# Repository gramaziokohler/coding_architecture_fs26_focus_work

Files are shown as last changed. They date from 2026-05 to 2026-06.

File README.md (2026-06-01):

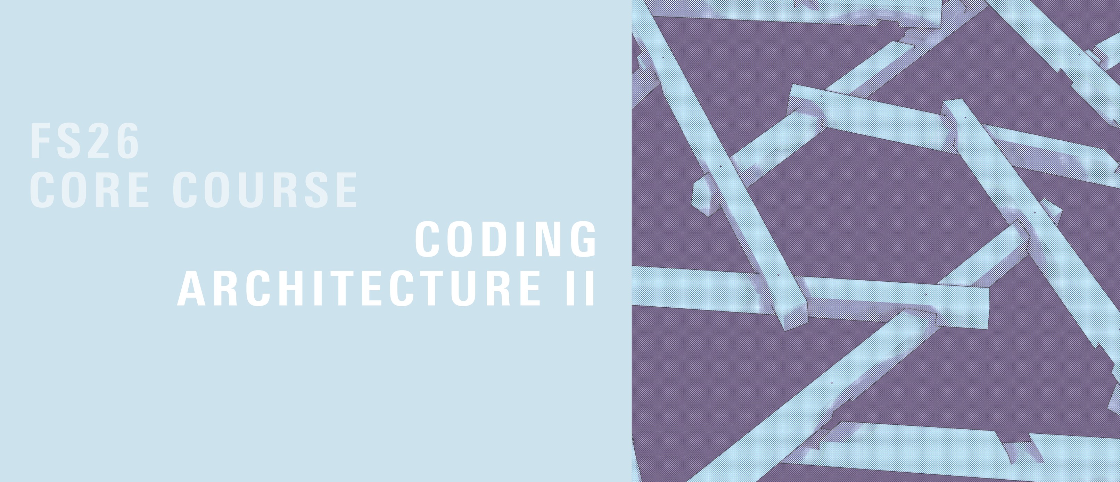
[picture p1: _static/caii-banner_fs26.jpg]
Banner


# Coding Architecture II: Focus Work

> **We are starting!**

Welcome to the **Focus Work** of Coding Architecture II, Spring Semester 2026! 

Following an intensive design phase, this repository focuses on the translation of the **winning project** into a real-world, full-scale timber structure. Over the next four weeks, we will adapt, refine, fabricate, and assemble the reciprocal frame structure for the local neighborhood garden (*Quartiergarten*).

This phase bridges the gap between computational design and physical reality, requiring a fabrication- and assembly-aware mindset from day one.

## Table of Contents
1. [Focuswork Overview & Schedule](#focuswork-overview--schedule)
   - [Week 1: Revision & Detailing](#week-1-revision--detailing)
   - [Week 2: Preparation & Machine Instructions](#week-2-preparation--machine-instructions)
   - [Week 3: Fabrication & Prefabrication](#week-3-fabrication--prefabrication)
   - [Week 4: On-Site Assembly](#week-4-on-site-assembly)
2. [Workflow & Team Structure](#workflow--team-structure)
   - [Dynamic Deliverables](#dynamic-deliverables)
3. [Repository Structure](#repository-structure)
   - [Working Folders vs. Deliverables](#working-folders-vs-deliverables)
   - [Group 3's Approach and changes to the default solution](#group-3s-approach-and-changes-to-the-default-solution)

---

## Focuswork Overview & Schedule

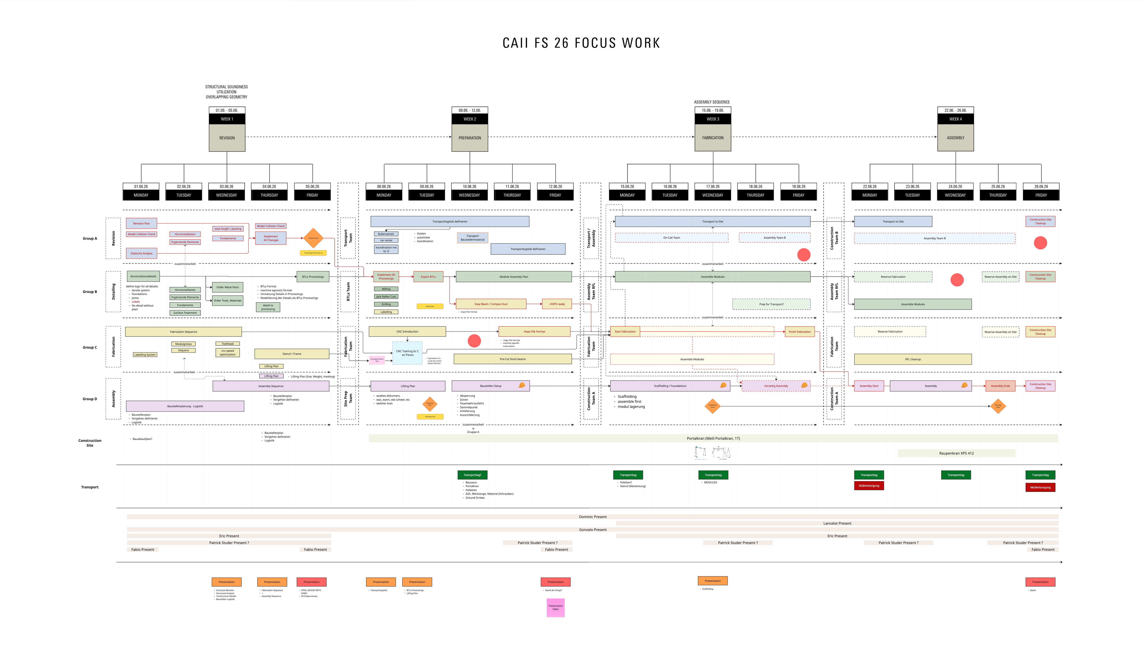
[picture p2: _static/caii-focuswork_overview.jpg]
Focus Work Overview


The Focus Work spans exactly 4 weeks (20 full working days), taking us from design refinement all the way to the final construction and Apero.

### Week 1: Revision & Detailing
**Goal: Design Freeze, Timber Model & BTLX Extraction**
* Integrate direct feedback and wishes from the *Quartiergarten* community.
* Resolve structural analysis and finalize construction details (foundations, connections, joints).
* Establish the fabrication and assembly sequence, including site planning and logistics.
* Design the physical template (*Schablone*) for pinpoint foundation placement.

### Week 2: Preparation & Machine Instructions
**Goal: System Ready for Fabrication**
* Prepare the CNC machine instructions and dive into the HOPS file format.
* Pre-cut all raw beams to their required stock length.
* Finalize the modular subdivision of the structure.
* Plan exact sequences, define transport logistics, and order the final remaining parts.

### Week 3: Fabrication & Prefabrication
**Goal: Transport-Ready Modules**
* Produce the foundation template and machine all custom timber parts.
* Assemble the parts into pre-fabricated modules simultaneously in the lab.
* Label all elements systematically and pack them to be transport-ready.

### Week 4: On-Site Assembly
**Goal: Full-Scale Construction**
* Transport all modules to the site.
* Use the template for accurate foundation placement.
* Assemble the modules into the final structure in a single day using a crane.
* Site teardown, tool cleanup, and concluding with a well-deserved Apero! 🍻

---

## Workflow & Team Structure

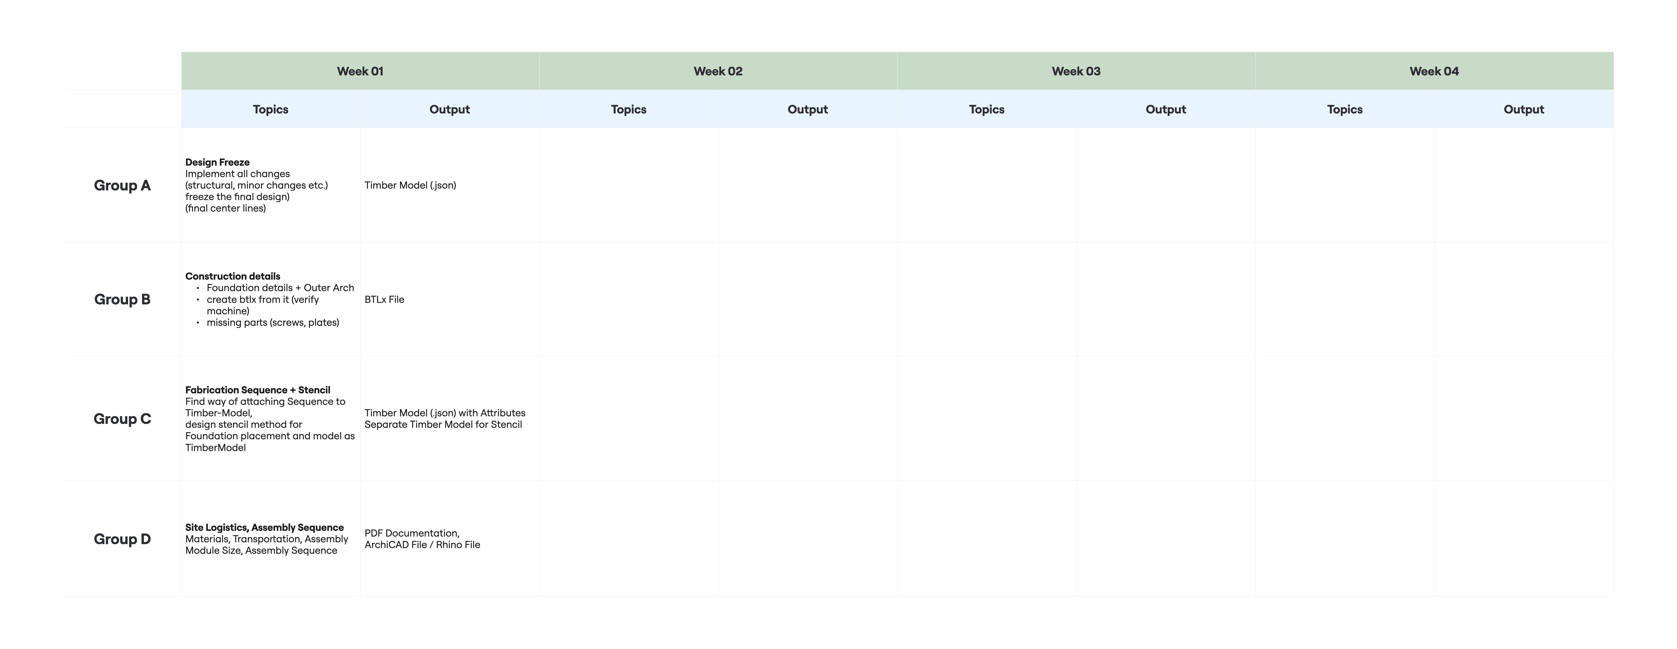
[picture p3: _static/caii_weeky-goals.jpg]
Weekly Goals


> *Note: This image will be updated soon.*

The cohort is divided into **4 Groups (A, B, C, D)**. 

To foster leadership and project management skills, **each group takes the primary responsibility for one specific week**, coordinating the tasks and ensuring the milestones are met.
    
### Dynamic Deliverables
Weekly deliverables will be announced on a rolling basis. The workflow will adapt to the reality of the project: sometimes it will be linear, sometimes circular and iterative. There will be highly intense periods and more relaxed ones. **Flexibility, communication, and teamwork are our most important tools.**

You will work across the organized sub-directories (`working_directory/group_a/`, `working_directory/group_b/`, `working_directory/group_c/`, `working_directory/group_d/`) and will heavily interact and hand off tasks between groups.

## Repository Structure

To keep the repository organized despite the dynamic and sometimes chaotic nature of the Focus Work, we strictly separate **work in progress** from **official milestones**. 

```text
coding_architecture_fs26_focus_work/
├── _static/             # Static files and assets for documentation
├── code/                # Core Python scripts and GH definitions
├── deliverables/        # Official weekly handovers
│   ├── week_01/
│   ├── week_02/
│   └── ...
├── design/              # Rhino files and base geometries
├── images/              # Additional project and progress images
├── timber_models/       # Exports of finalized timber objects/models
└── working_directory/   # Sandboxes for the groups
    ├── group_a/         # Working directory for Group A
    ├── group_b/         # Working directory for Group B
    ├── group_c/         # Working directory for Group C
    └── group_d/         # Working directory for Group D
```

### Working Folders vs. Deliverables
* **`working_directory/group_*/` Folders:** Your primary sandbox. This is where your group edits scripts, tests parametric components, experiments with new tools, and saves intermediate Grasshopper files. Each group has full ownership over their folder.
* **`deliverables/week_XX/` Folders:** At the end of each week, the responsible lead group compiles the finalized code, the frozen Rhino models, fabrication files (like BTLX/HOPS), and logistic lists into the respective week's folder. This guarantees a clean, linear history of our progress without the clutter of daily work.
* **`code/` & `design/`:** Shared global resources. The `code/` folder contains the core algorithmic pipeline that we refine together.

### Group 3's Approach and changes to the default solution
The codebase provided here is based on the winning design from the semester. Group 3 distinguished themselves by heavily extending our standard reciprocal frame template to bridge the gap between automated generation and manual control. Here is how their approach stands out and which files drive it:
    
1. **Dual-Mesh Generation:** Instead of applying one algorithm to the whole structure, they generate a hexagonal mesh for the interior beams and a quad mesh for the boundary beams.
2. **Custom RF Logic (`a03_rf_system_timo.py`):** They authored custom reciprocal frame logic for the inner beams to introduce specifically tailored hexagonal eccentricity and beam extensions, while keeping the boundary beams simple (`a03_rf_system.py`).
3. **Interactive Line Editing (C# Component):** They merged the beams (`a03_line_cleaner.py`), extracted the pure centerlines, and passed them into a custom C# Grasshopper component. This script creates an interactive GUI in Rhino (with custom Snaps and a mini-Gumball) that allows developers to manually drag and adjust specific beam endpoints visually.
4. **The Hybrid System (`a03_rf_system_hybrid.py`):** Because moving independent lines manually breaks the original continuous mesh topology, they wrote a script that intelligently pieces the edited loose lines back together into a valid, combined `RFSystemHybrid` mesh graph.
5. **Custom Foundation Rules:** By subclassing the default timber model creator, we have started to implemented specific rules to automatically identify foundation beams (beams lying horizontally near `z=0`), assign them a stronger 110x120 cross-section, and apply specific structural joints.

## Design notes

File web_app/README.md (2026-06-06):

# Vue 3 + Vite

This template should help get you started developing with Vue 3 in Vite. The template uses Vue 3 `<script setup>` SFCs, check out the [script setup docs](https://v3.vuejs.org/api/sfc-script-setup.html#sfc-script-setup) to learn more.

Learn more about IDE Support for Vue in the [Vue Docs Scaling up Guide](https://vuejs.org/guide/scaling-up/tooling.html#ide-support).

## Regenerate `web_data` from a TimberModel

The web app does not read `timber_models/*.json` directly. It reads the split
viewer export in `web_data/`:

- `web_data/structure.json`
- `web_data/beams/<beam_id>/<beam_id>.json`
- `web_data/beams/<beam_id>/<beam_id>.stl`

For final joinery geometry, use the Grasshopper component script:

```text
code/gh_compont_scripts/gh_export_web_data.py
```

It takes the live TimberModel object, runs inside Rhino, and can therefore use
`model.process_joinery()` and `beam.geometry` with Rhino's BRep backend.

To regenerate that folder from a TimberModel JSON:

```bash
python ../code/export_web_data.py ../timber_models/timber_model_friday-3.json --output ../web_data --clean
```

By default the exporter uses `--geometry-source auto`: it tries to load the
TimberModel with COMPAS Timber, runs `model.process_joinery()`, and writes STL
files from each processed `beam.geometry`. If COMPAS Timber is not available, or
if a beam geometry cannot be converted to a mesh, that beam falls back to a
rectangular STL from `frame`, `length`, `width`, and `height`.

To require real COMPAS Timber geometry and fail instead of falling back:

```bash
python ../code/export_web_data.py ../timber_models/timber_model_friday-3.json --output ../web_data --clean --geometry-source compas
```

When using the Rhino 8 Python site env on Apple Silicon, run the x86_64 Python
because the installed binary packages are x86_64:

```bash
PYTHONPATH=/Users/lorinwiedemeier/.rhinocode/py39-rh8/site-envs/ca-fs26-focus-work-p_hXDUpu \
arch -x86_64 /Users/lorinwiedemeier/.rhinocode/py39-rh8/python3.9 \
../code/export_web_data.py ../timber_models/timber_model_friday-3.json --output ../web_data --clean
```

If this prints `PluginNotInstalledError` for `Brep`, the script is running
outside a Rhino context and COMPAS cannot evaluate the final BRep geometry. In
that case the exporter still writes metadata and box fallback STLs, but final
joinery STLs need to be exported from inside Rhino/GH or from a Python runtime
with a working COMPAS BRep plugin.

The exporter first looks for beam identity values in beam attributes, so Group C
can later store names/modules/numbers there without changing the rest of the
export. The fallback naming is sequential and uses:

```bash
--module-sizes A:36,B:31,C:30,D:27,E:27,F:31
```

The script writes valid STL files. In an environment with COMPAS Timber, those
STLs should include processed joinery. Outside that environment, the STL fallback
is only the rectangular beam volume.

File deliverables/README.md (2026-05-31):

# Deliverables & Submission Table

| Group | Week 01 |
| :--- | :--- |
| **Group A** | **Topics:**<br>- Design Freeze<br>- Implement Changes/Adjustments from Quartiergarten (by tuesday evening)<br>- Implement Structural Analysis results (starting wed or thu)<br>- Collision Checks<br>- Setup a clean Timbermodel creation in coordination with Group B<br>- Ensure all joints are drawn properly (Linked to Group B)<br>- Ensure foundations and outer arch can be controlled separately (Linked to Group B)<br>- Design Decisions: definitive orientation and placement, definitive size and shape<br>- DESIGN FREEZE!<br><br>**Output:**<br>- Timber Model (.json)<br>- Grasshopper file (.ghx)<br>- Karamba-Mesh (.3dm)<br>- RSTAB File (.rs9) |
| **Group B** | **Topics:**<br>- Construction details<br>- Define & implement details: foundation (Linked to Group A), outer arch (Linked to Group A)<br>- Create processings<br>- Predrillings<br>- Name engravings (Linked to Group C)<br>- Export BTLx<br>- Order assembly parts (screws, plates)<br><br>**Output:**<br>- TimberModel (.json)<br>- Grasshopper (.ghx)<br>- Machining File (.btlx) |
| **Group C** | **Topics:**<br>- Fabrication Sequence + Stencil<br>- Define a way of attaching fabrication sequence to Timber-Model<br>- Define fabrication-module size (Linked to Group D)<br>- Define fabrication sequence (Linked to Group D)<br>- Design stencil method for Foundation placement and model as TimberModel<br>- Create naming convention for elements and modules<br><br>**Output:**<br>- Timber Model (.json) with Attributes<br>- GH File (.ghx) w/ Sequencing<br>- Explanatory animation or diagram<br>- Separate Timber Model for Stencil |
| **Group D** | **Topics:**<br>- Site Logistics, Assembly Sequence<br>- Plan for materials and transportation<br>- Define assembly-module size (Linked to Group C)<br>- Plan assembly sequence (Linked to Group C)<br>- Create transportation plan, assembly plan, construction site plan<br><br>**Output:**<br>- PDF Documentation (.pdf)<br>- A2 Plot of Plan (physical)<br>- Grasshopper file (.ghx)<br>- ArchiCAD File / Rhino File (.pln / .3dm) |

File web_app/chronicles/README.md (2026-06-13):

# Hardleaf — Coding Chronicles

A 3D skyline visualization of the Hardleaf repository's evolution. Each tower is a
commit; height is lines changed, color is the add/delete balance, and the camera
flies down the avenue of time while commit messages surface in the ticker.

## How the data flow works

The page loads `commits.json` (fetched next to `index.html`) on open. That file is
**generated by a GitHub Action and published with the Pages deployment** — it is
never committed to the repository. If `commits.json` is missing (e.g. opening the
HTML locally), the page falls back to built-in demo data, so it always renders.

This app does **not** have its own Pages deployment. GitHub Pages allows only one
deployment per repo, and that slot is owned by the main `web_app` (Vite) site. To
avoid clobbering it, the skyline is built as a step inside the main deploy workflow
and dropped into a `chronicles/` subfolder of the main app's `dist/`:

```
repo/
├─ web_app/
│  └─ chronicles/
│     ├─ index.html              # this page (deployed at /chronicles/index.html)
│     ├─ build-commits.mjs       # generates commits.json from git history
│     └─ README.md               # you are here
└─ .github/workflows/
   └─ deploy.yml                 # builds web_app + this skyline, deploys both
```

The relevant steps in [`.github/workflows/deploy.yml`](../../.github/workflows/deploy.yml):

```yaml
- uses: actions/checkout@v4
  with:
    fetch-depth: 0              # generator needs full commit history
# ...build main app into web_app/dist...
- run: |
    mkdir -p web_app/dist/chronicles
    cp web_app/chronicles/index.html web_app/dist/chronicles/index.html
    node web_app/chronicles/build-commits.mjs --out web_app/dist/chronicles/commits.json
```

So the main app stays at the site root and the skyline is served at the
`/chronicles/` subpath, e.g.
`https://<owner>.github.io/coding_architecture_fs26_focus_work/chronicles/`.
Because the page fetches `./commits.json` (relative), the subpath needs no code change.

The workflow runs on every push to `main`, once daily, and on manual dispatch, so the
skyline stays current with no manual step.

## Local preview

`commits.json` won't exist locally, so the page shows demo data. To preview against
real data, generate it yourself and serve the folder (a plain file:// open will not
fetch JSON in some browsers):

```bash
# from web_app/chronicles/
node build-commits.mjs --out commits.json
python3 -m http.server 8000     # then visit http://localhost:8000/index.html
```

## Options

- **Full history vs. trailing month.** The workflow generates full history by
  default. For only the last 30 days, change the generate step in `deploy.yml` to:
  `node web_app/chronicles/build-commits.mjs --since "30 days ago" --out web_app/dist/chronicles/commits.json`
- **Manual override.** The "Load your repo" drawer in the page still works for
  pasting any `git log` output by hand.

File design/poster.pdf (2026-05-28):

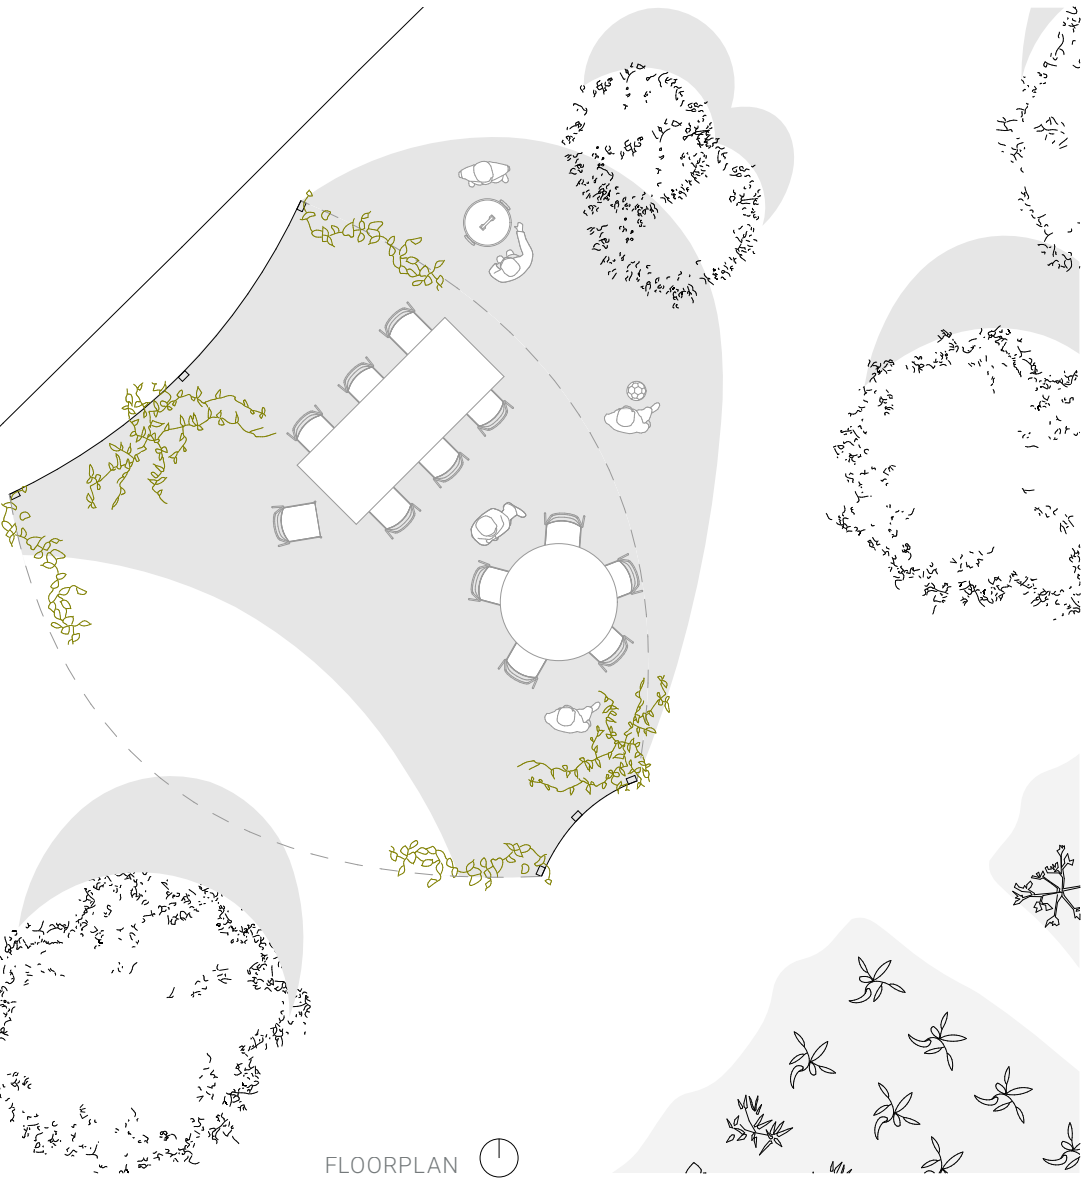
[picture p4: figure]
FLOORPLAN

GSEducationalVersion

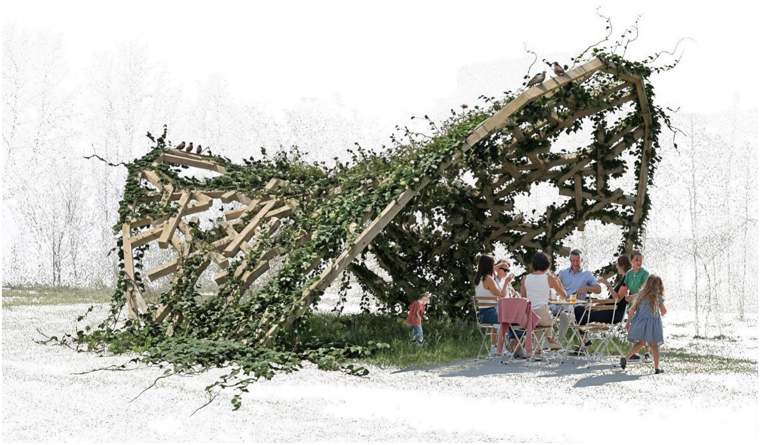
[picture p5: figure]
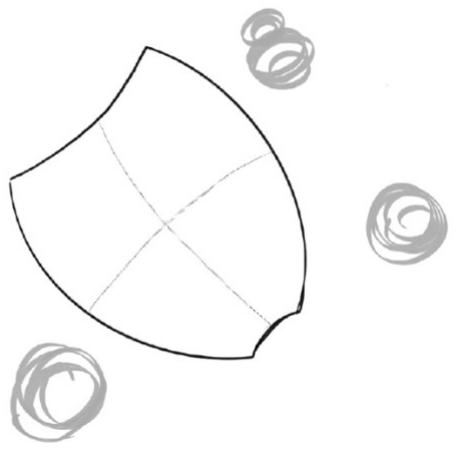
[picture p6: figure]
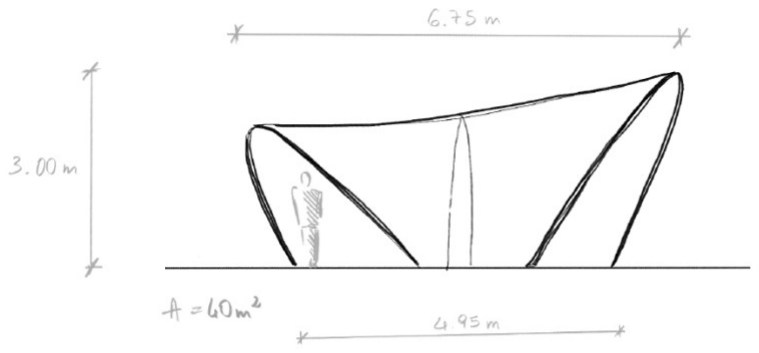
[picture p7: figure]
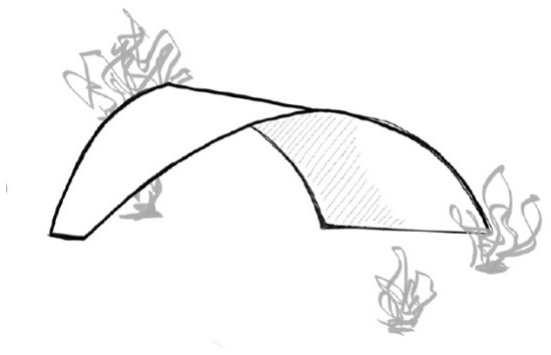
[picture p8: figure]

SKETCHES

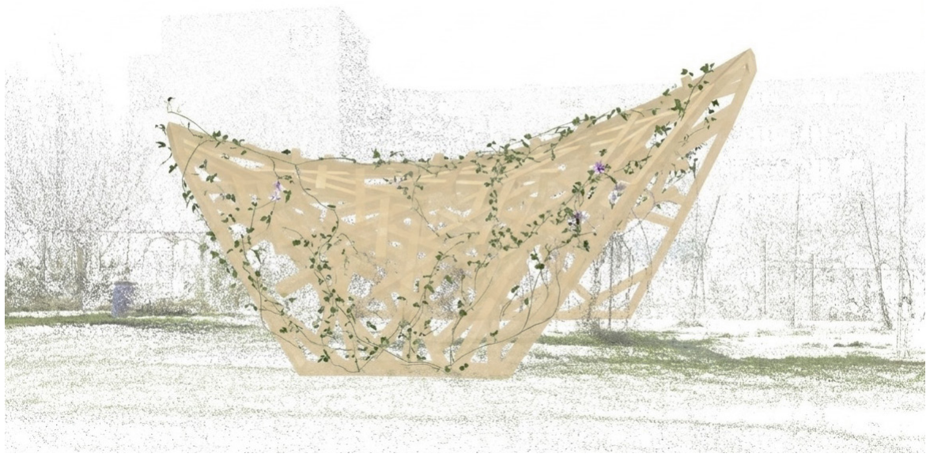
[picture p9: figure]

MESHING WORKFLOW

The pavilion was conceived through a design process focused on preserving and enhancing the existing vegetation of the garden. Particular attention was given to the plum tree and the banana trees, which emerged during the site visit as important and valued elements of the space. Rather than imposing a new object onto the site, the project was developed as an organic intervention integrated around the presence of these plants.

As the design evolved, the geometry was refined to maximize shaded areas and improve environmental comfort. This led to the development of a leaf-shaped configuration, characterized by variations in height and a wider canopy capable of providing extensive coverage while maintaining a projected area of 40 m². The pavilion retains a clear and simple structural logic based on two load-bearing sides: a longer structural edge positioned parallel to the existing fence at the back of the garden, and a shorter side at the front, opening the pavilion towards the landscape.

The orientation of the structure directly informs its form. On the south side, the pavilion remains lower in height to strengthen protection from direct sunlight, working together with the natural shade provided by the nearby plum tree. Towards the north, the structure gradually opens and rises, creating a lighter and more permeable spatial condition.

The covered area was intentionally designed as a wide and open space, ensuring flexibility and adaptability for different uses over time. The pavilion can accommodate tables, gatherings, workshops, or temporary installations, while remaining open to future transformations and changing configurations of plants within the garden.

The project also responds to the current condition of the kiwi plants located in the center of the site. Since relocating them immediately may not be possible, the pavilion allows for multiple scenarios: the plants can temporarily remain within the open interior space or later be repositioned along the structural base, where they could continue growing integrated with the pavilion itself while keeping the central area unobstructed.

# HARD LEAF

TIMO FEDDERN, ZAN KOCUNIK, ALESSIA MARTINO
GROUP 03 / CODING ARCHITECTURE II / FS26

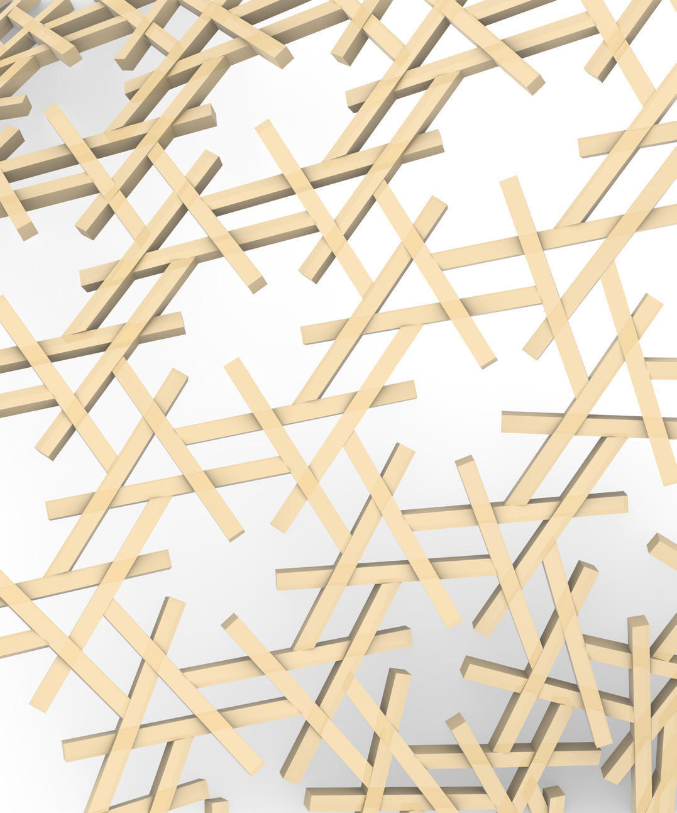
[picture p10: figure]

The | reciprocal | frame
structure | is | generated
through an organic meshing system derived from a
hexagonal pattern. Starting from a regular geometric grid, the mesh was progressively transformed and adapted to create a more fluid and natural configuration. The resulting network combines order and irregularity: the hexagonal geometry provides structural continuity and stability, while the variation in orientation and density creates a lighter, more dynamic spatial effect. The differentiated density of the mesh also allows the structure to accommodate
multiple configurations of hanging plants and climbing vegetation, creating areas with varying levels of shade, openness, and interaction
with the surrounding garden.

View in AR!

QUARTIERGARTEN HARD, ZURICH

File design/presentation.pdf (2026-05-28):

# group 03

# Timo Feddern, Zan Kocunik, Alessia Martino

## Quartiergarten Hard Project Proposal

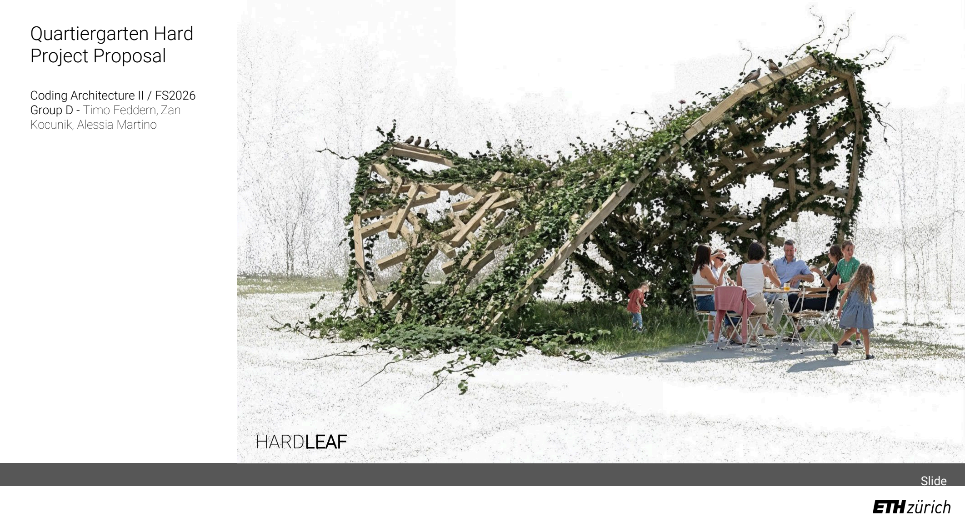
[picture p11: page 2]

Slide

## HARDLEAF

Coding Architecture II / FS2026 Group D - Timo Feddern, Zan Kocunik, Alessia Martino

## Design process

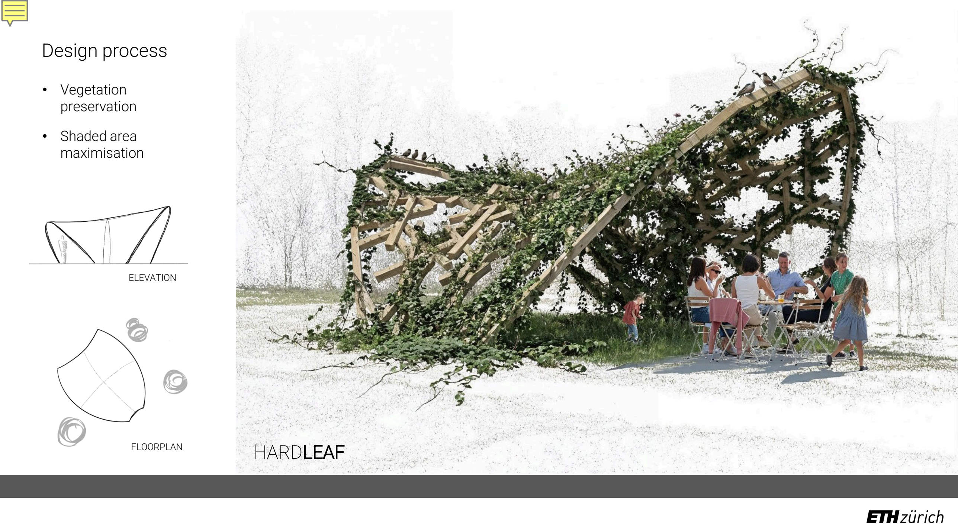
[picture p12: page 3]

## HARDLEAF

- Vegetation
preservation
- Shaded area
maximisation

ELEVATION

FLOORPLAN

## Context

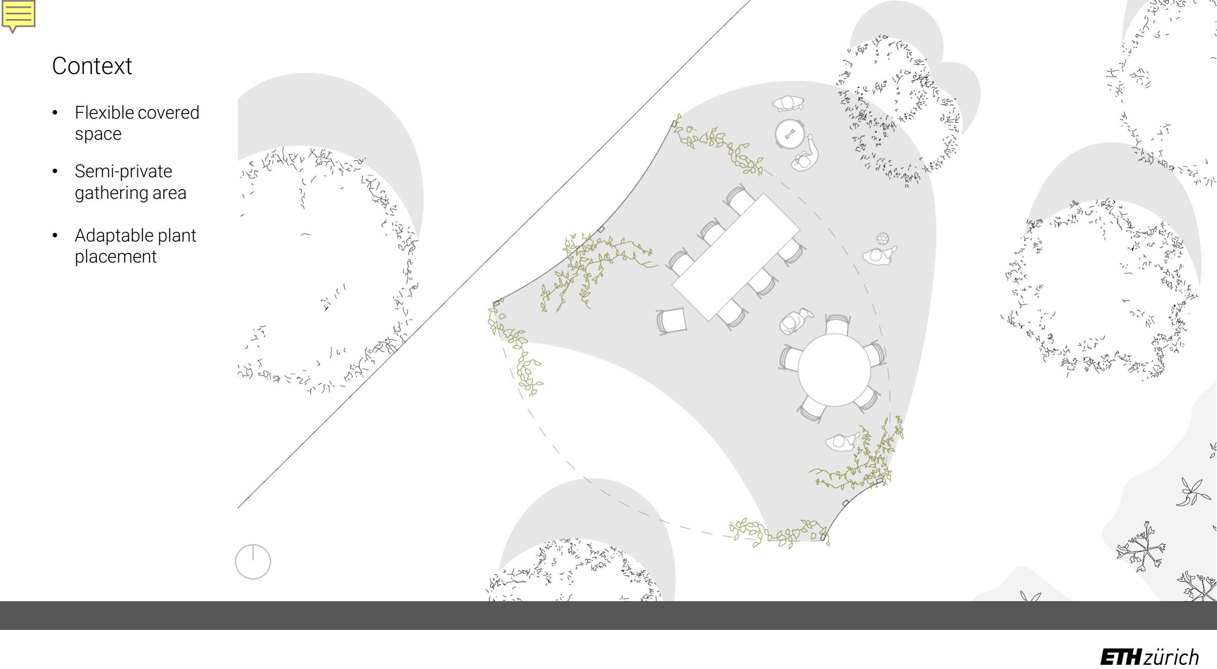
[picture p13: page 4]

- Flexible covered
space
- Semi-private
gathering area
- Adaptable plant
placement

## Exposure

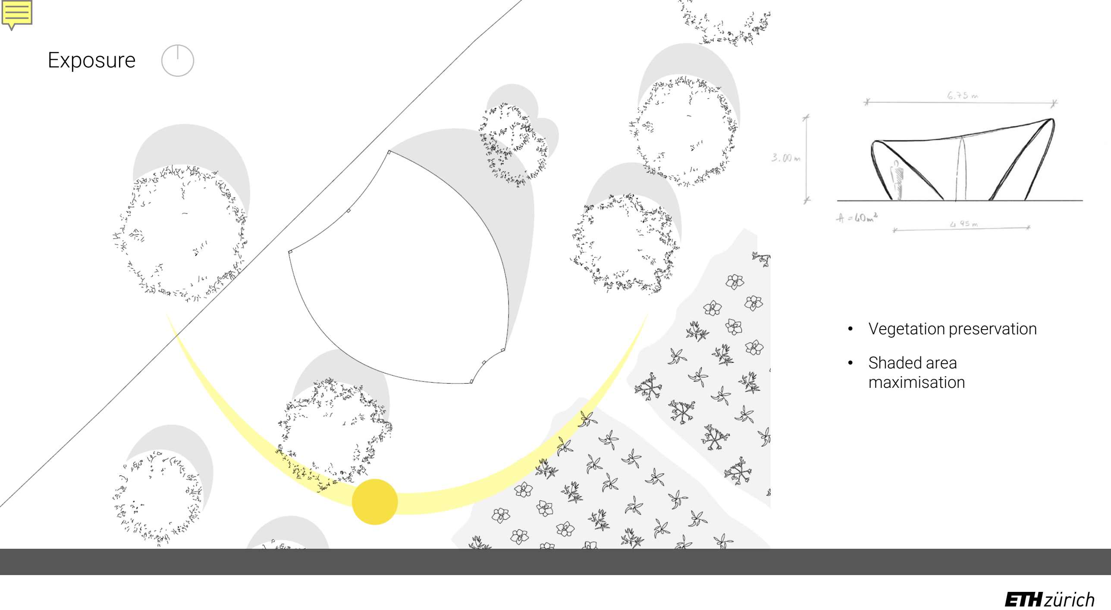
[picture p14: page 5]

- Vegetation preservation
- Shaded area
maximisation

## Reciprocal frame system

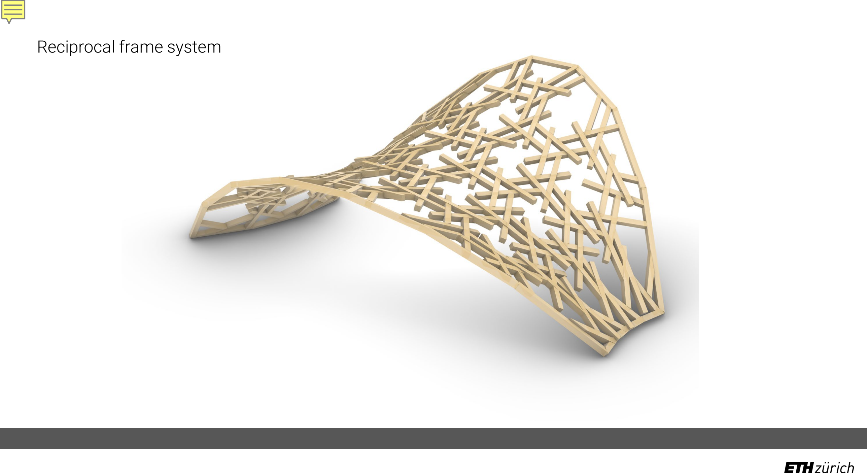
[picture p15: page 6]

## Meshing workflow

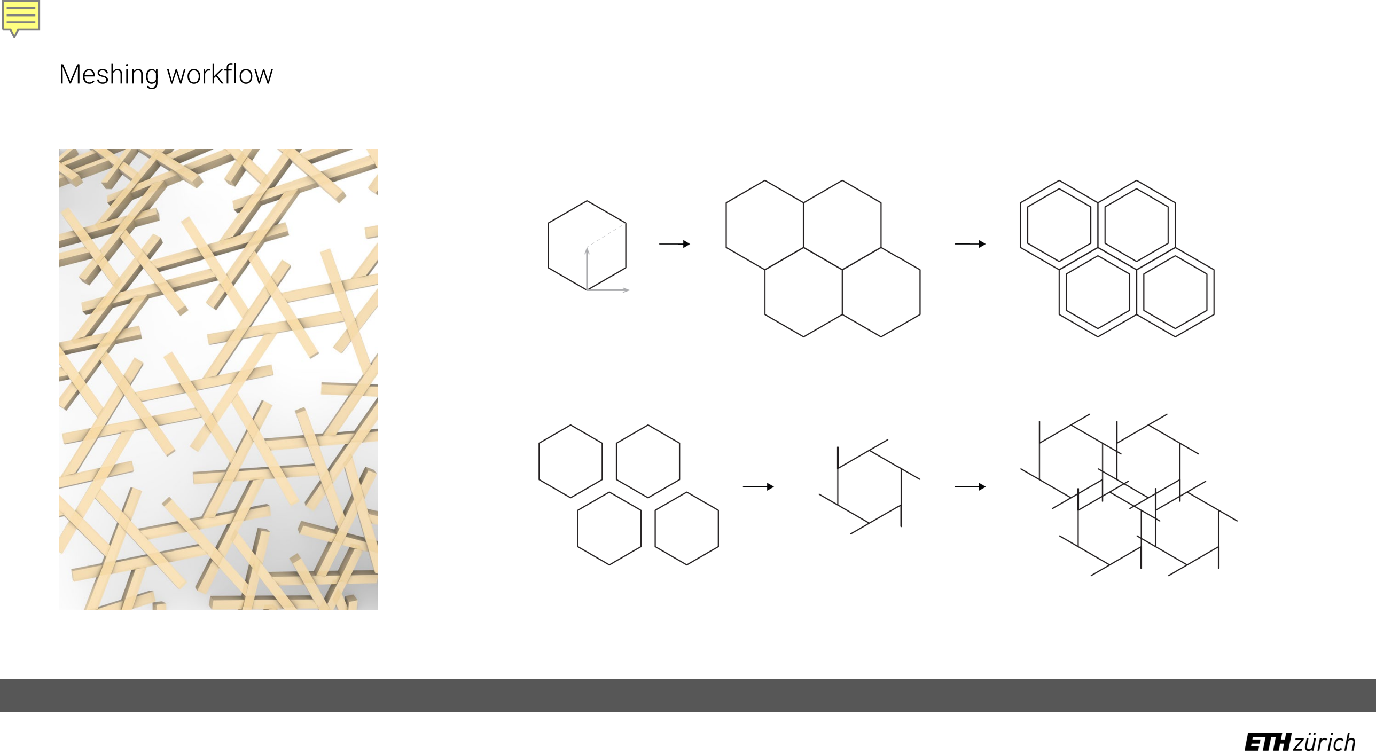
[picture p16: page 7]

## Shading

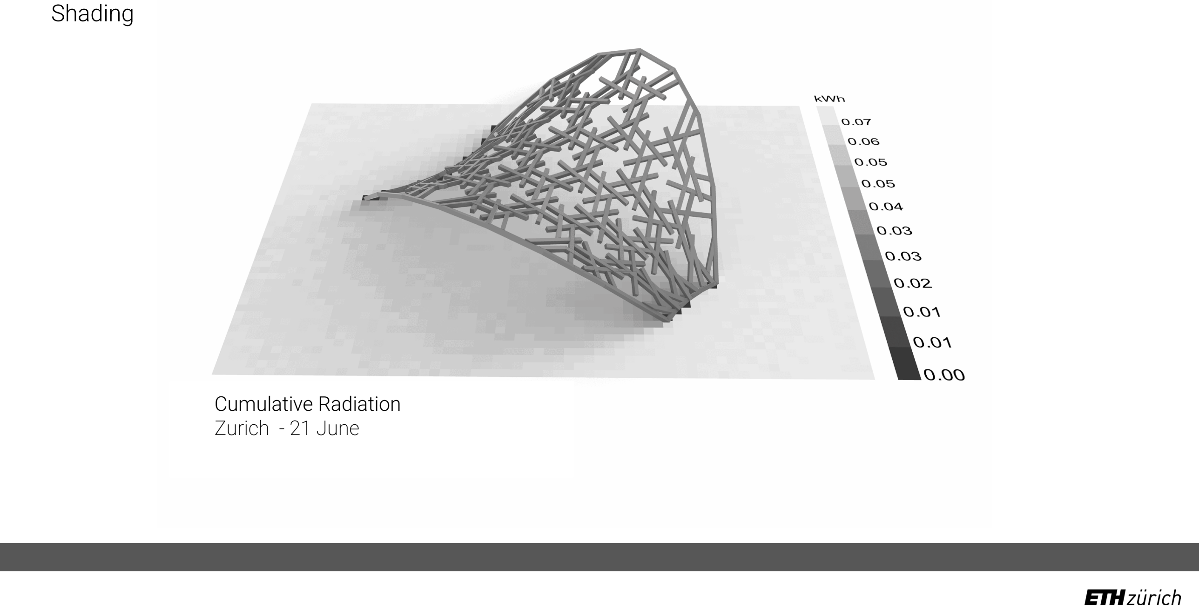
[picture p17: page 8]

Cumulative Radiation
Zurich - 21 June

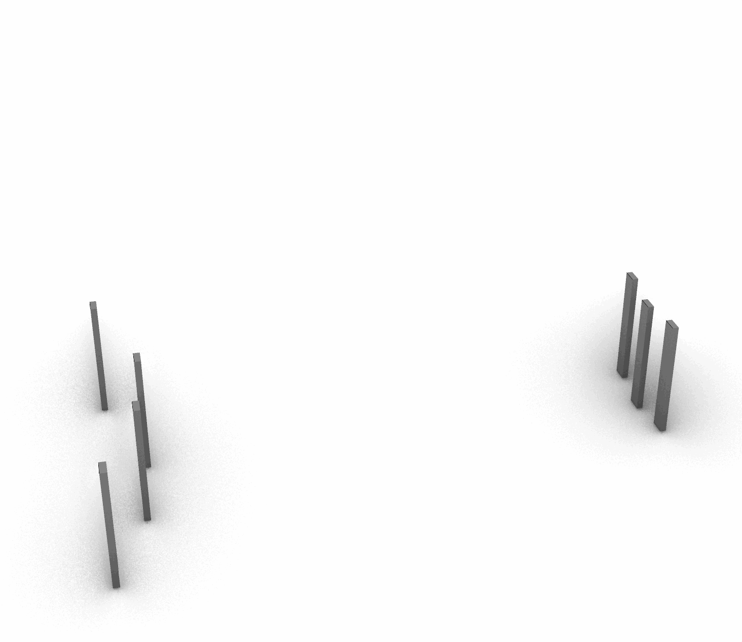
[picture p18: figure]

## Assembling

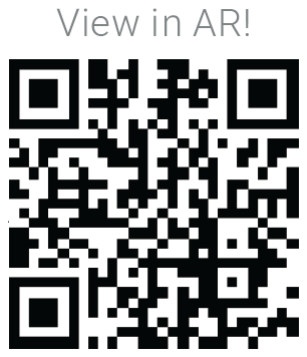
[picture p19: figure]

Thank you for your attention

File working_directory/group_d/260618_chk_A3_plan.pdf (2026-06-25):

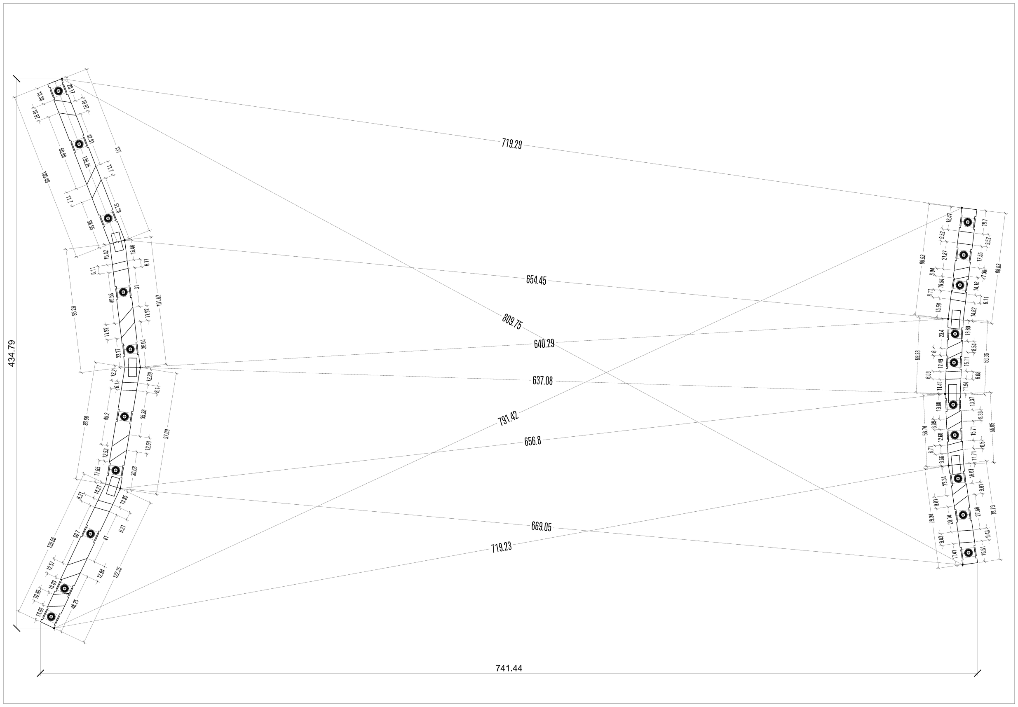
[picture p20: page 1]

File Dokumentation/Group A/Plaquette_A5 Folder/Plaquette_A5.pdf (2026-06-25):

# HARDLEAF

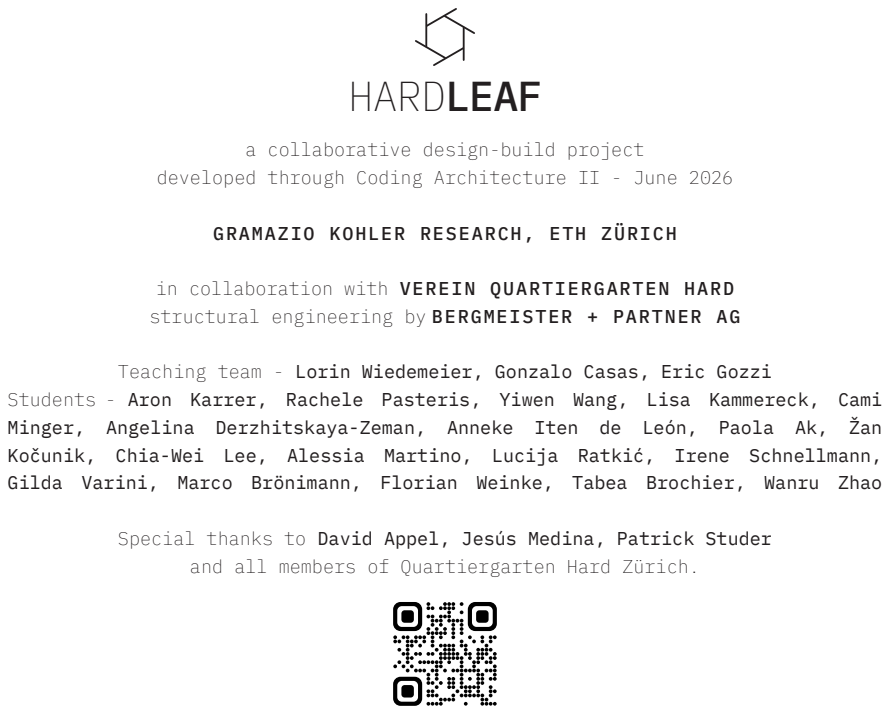
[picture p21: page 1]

a collaborative design-build project

developed through Coding Architecture II - June 2026

GRAMAZIO KOHLER RESEARCH, ETH ZÜRICH

in collaboration with VEREIN QUARTIERGARTEN HARD
structural engineering by BERGMEISTER + PARTNER AG

Teaching team - Lorin Wiedemeier, Gonzalo Casas, Eric Gozzi

Students - Aron Karrer, Rachele Pasteris, Yiwen Wang, Lisa Kammereck, Cami
Minger, Angelina Derzhitskaya-Zeman, Anneke Iten de León, Paola Ak, Žan
Kočunik, Chia-Wei Lee, Alessia Martino, Lucija Ratkić, Irene Schnellmann,
Gilda Varini, Marco Brönimann, Florian Weinke, Tabea Brochier, Wanru Zhao

Special thanks to David Appel, Jesús Medina, Patrick Studer
and all members of Quartiergarten Hard Zürich.

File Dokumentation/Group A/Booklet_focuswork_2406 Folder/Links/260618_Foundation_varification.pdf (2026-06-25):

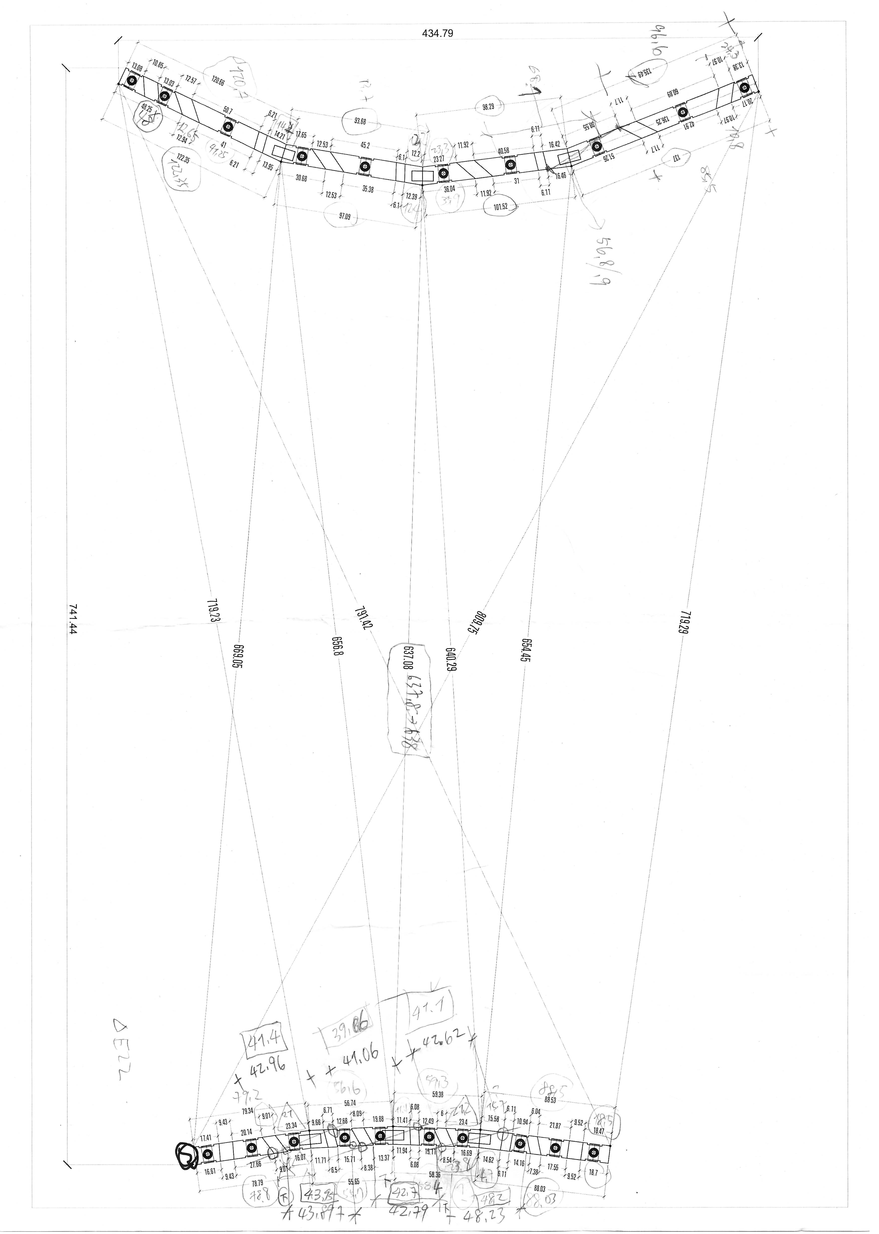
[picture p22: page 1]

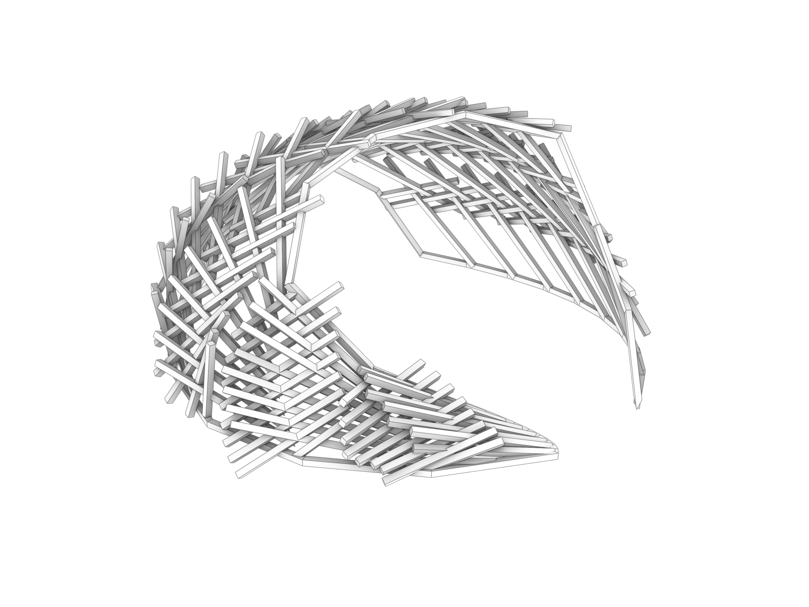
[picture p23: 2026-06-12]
Dokumentation/Design Task/Group_2.png

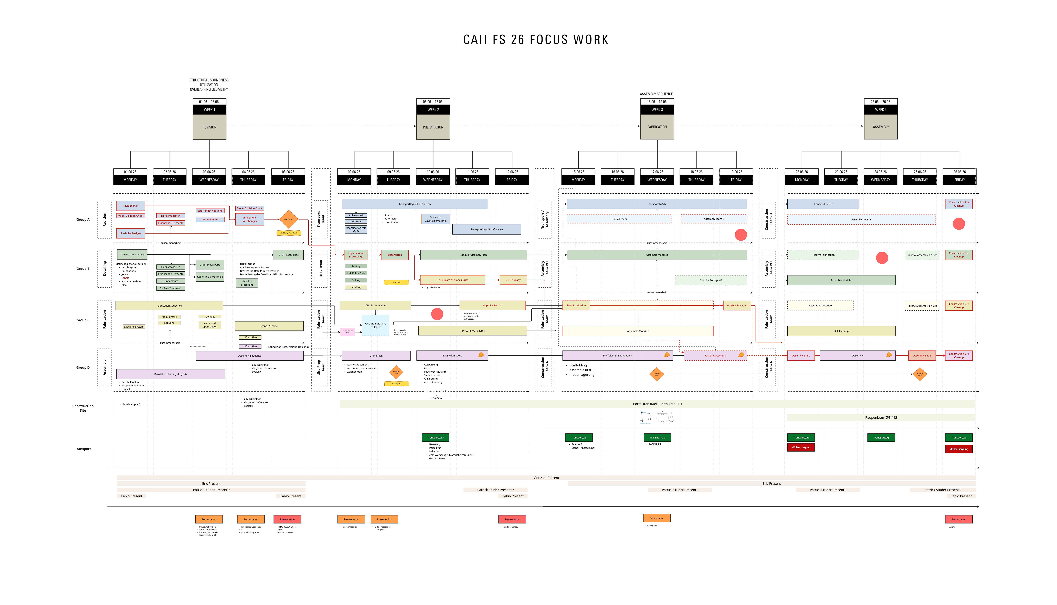
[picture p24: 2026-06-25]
Dokumentation/Group A/Booklet_focuswork_2406 Folder/Links/CAII - FS26 - Focus Work Overview_full.jpg

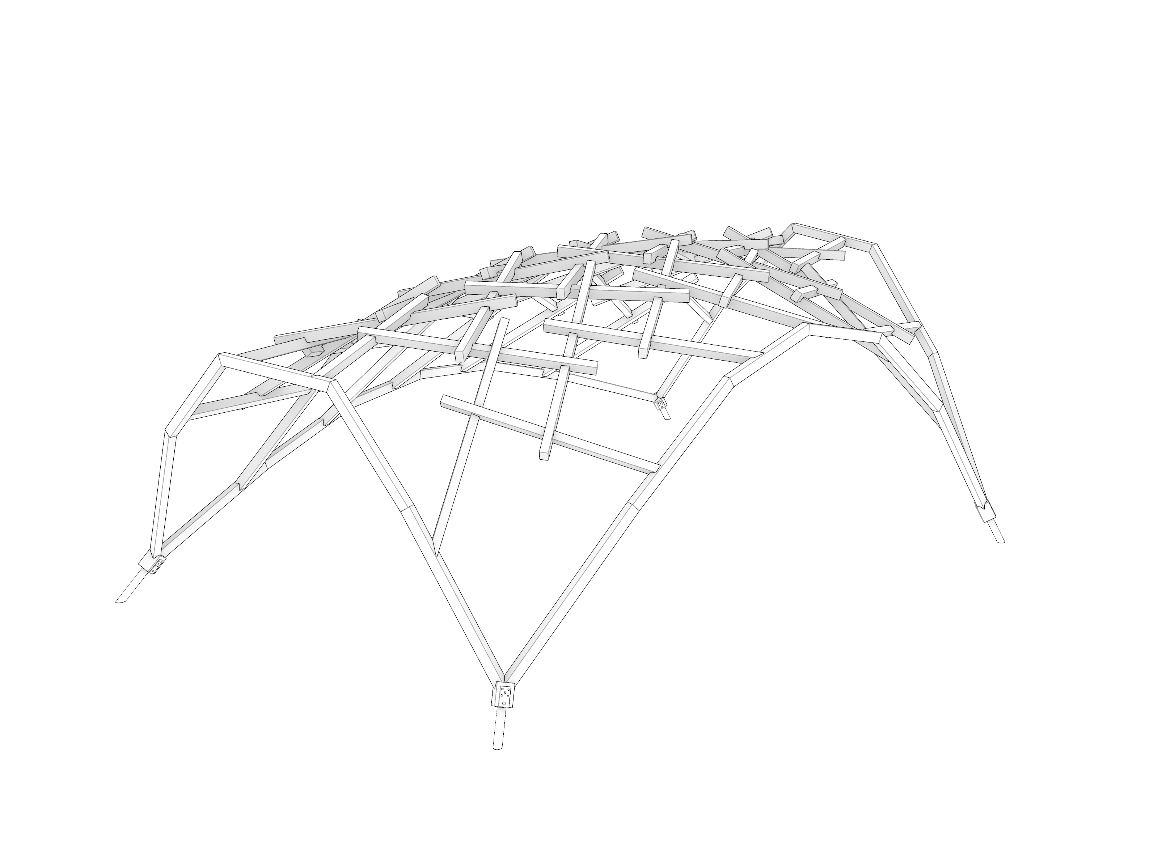
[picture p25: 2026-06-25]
Dokumentation/Design Task/Group06.png

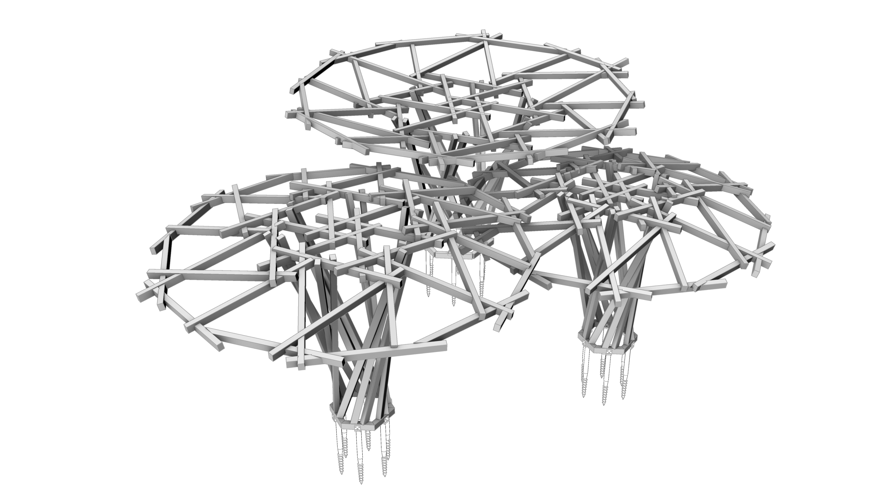
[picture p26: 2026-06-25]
Dokumentation/Design Task/Group_13.png

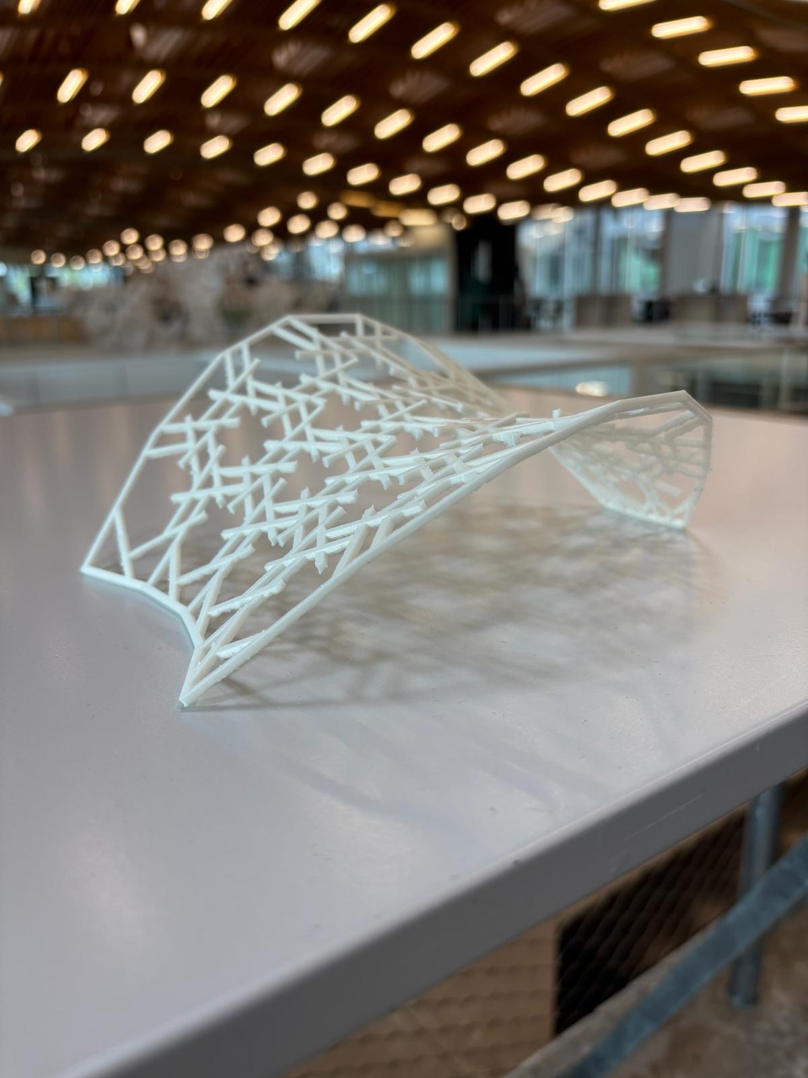
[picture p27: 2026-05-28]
images/3d_model.jpg

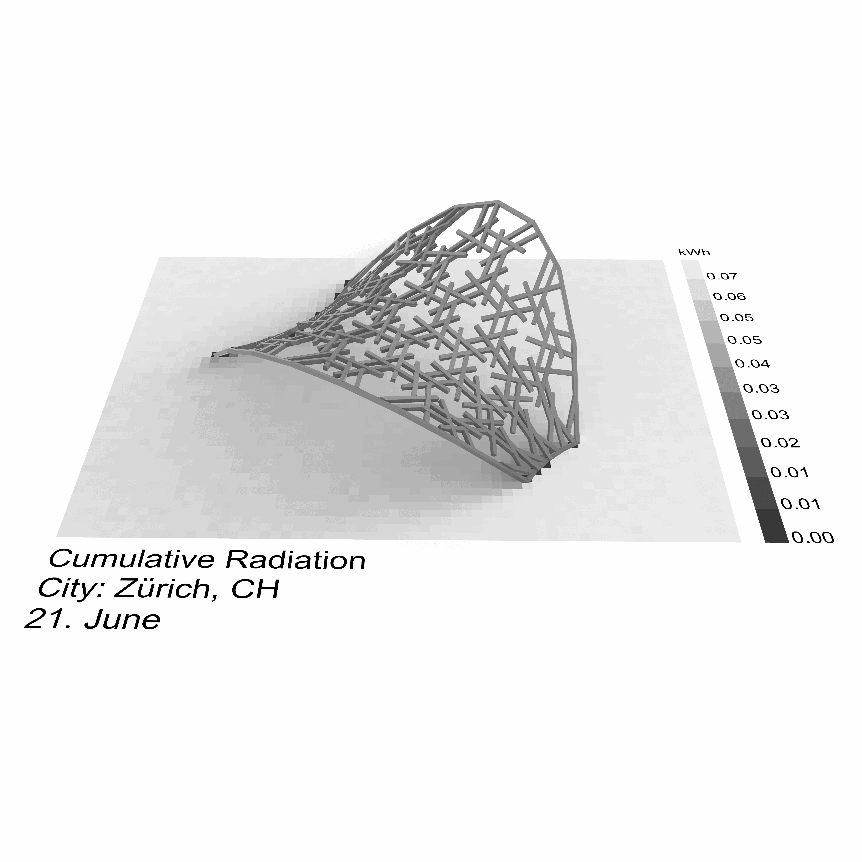
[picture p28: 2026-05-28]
images/cumulative_radiation.gif

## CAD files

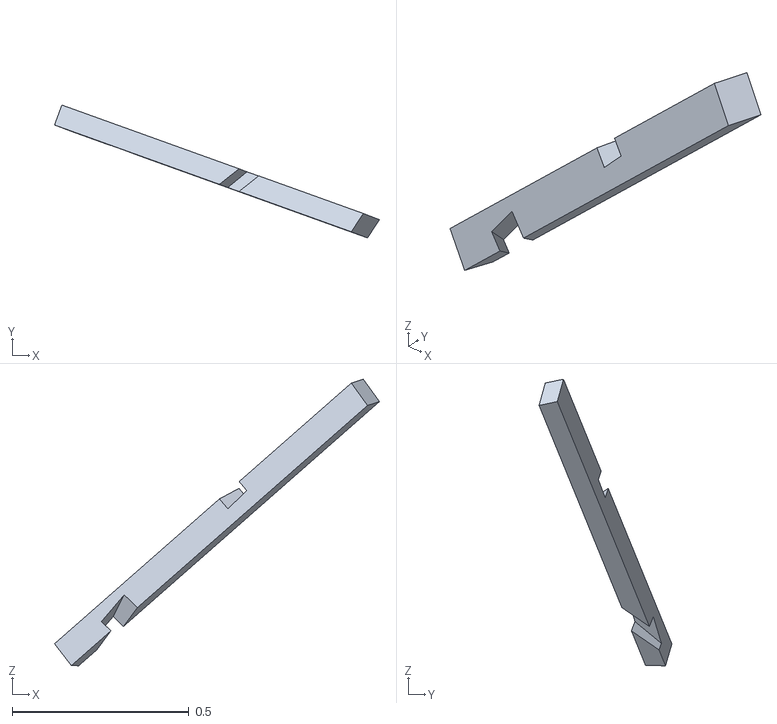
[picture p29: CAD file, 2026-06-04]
web_data/beam/a1/a1.stl
0.918 x 0.376 x 0.81

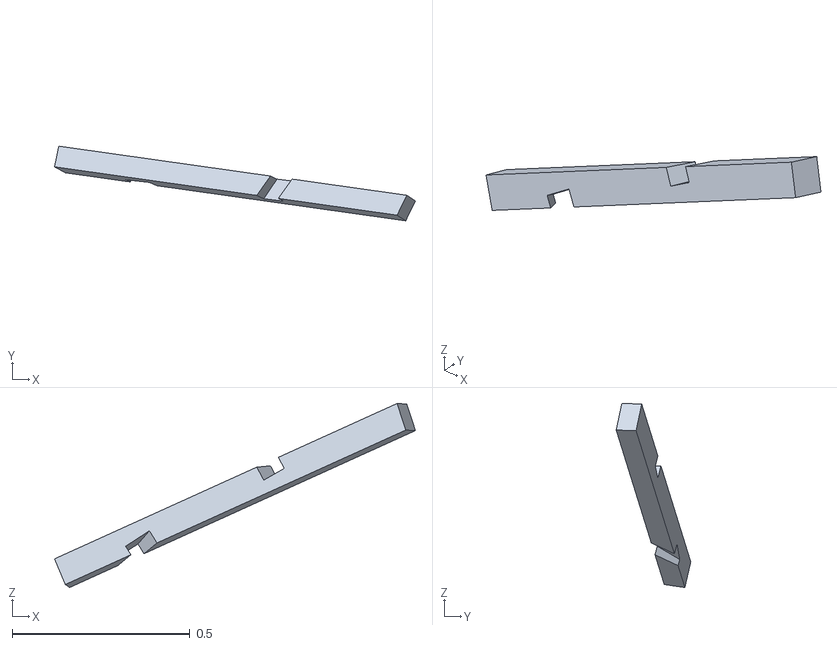
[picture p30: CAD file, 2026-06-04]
web_data/beam/a10/a10.stl
1.02 x 0.21 x 0.518

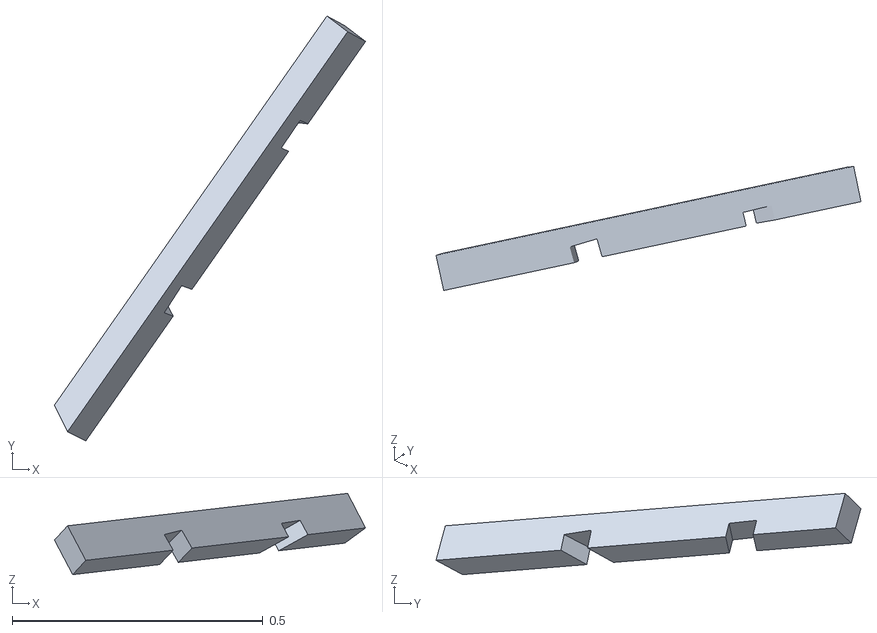
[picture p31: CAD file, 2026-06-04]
web_data/beam/a11/a11.stl
0.62 x 0.847 x 0.162

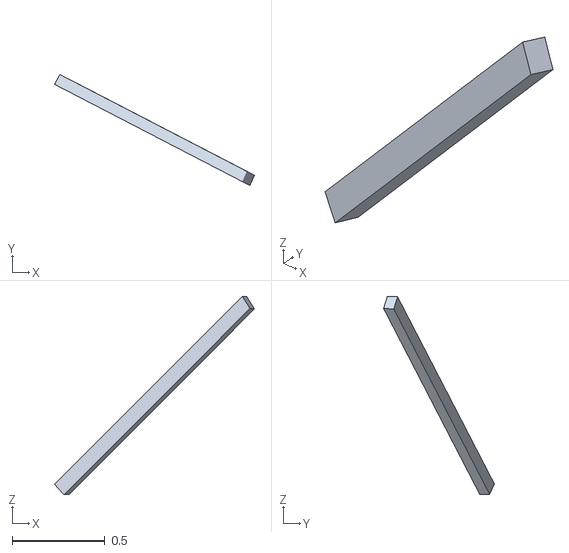
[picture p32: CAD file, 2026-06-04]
web_data/beam/a12/a12.stl
1.08 x 0.597 x 1.07

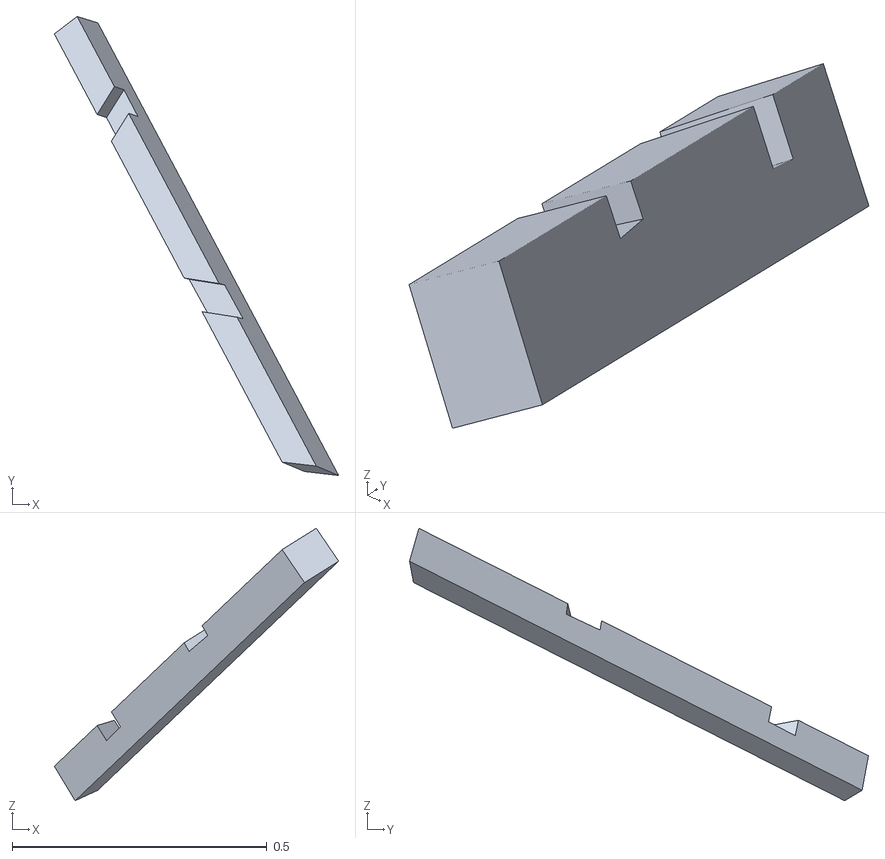
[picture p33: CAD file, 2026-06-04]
web_data/beam/a13/a13.stl
0.558 x 0.901 x 0.535

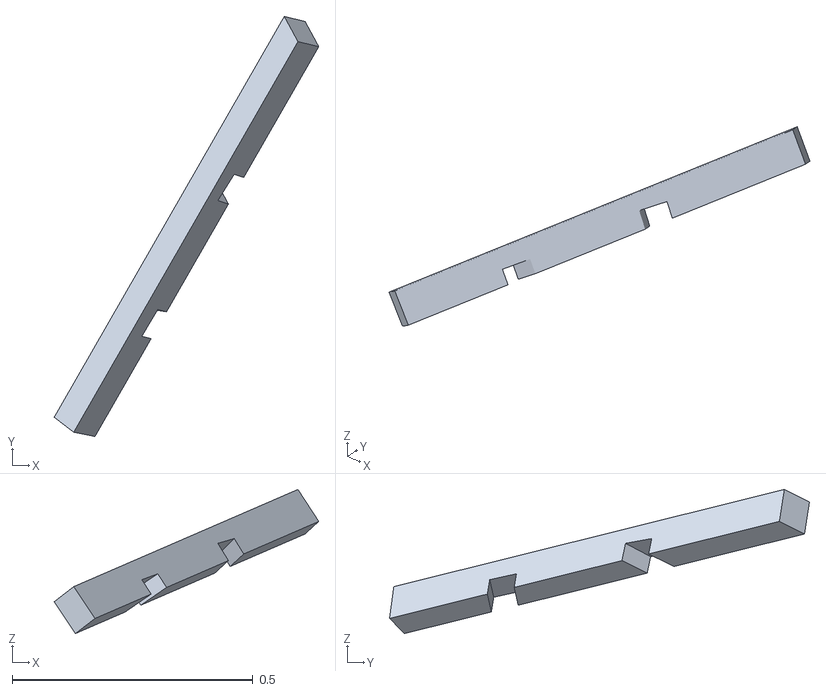
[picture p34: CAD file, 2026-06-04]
web_data/beam/a14/a14.stl
0.55 x 0.873 x 0.3

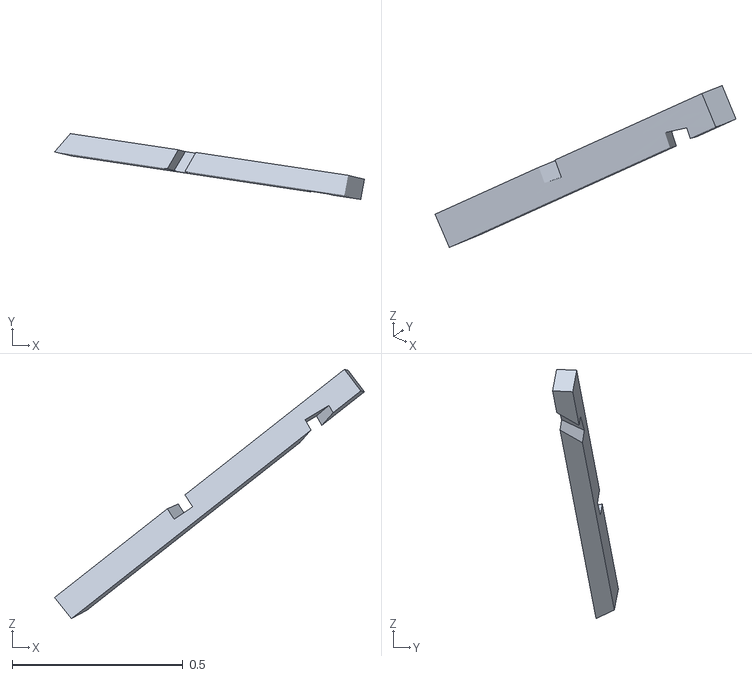
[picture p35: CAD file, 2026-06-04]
web_data/beam/a15/a15.stl
0.907 x 0.193 x 0.729

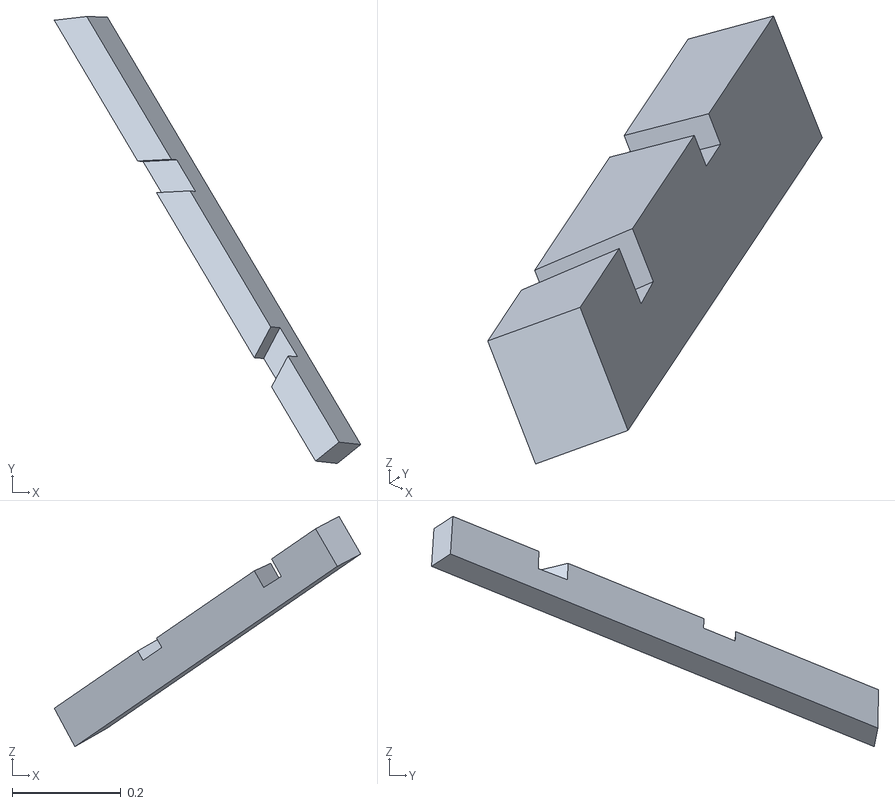
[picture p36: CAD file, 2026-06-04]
web_data/beam/a16/a16.stl
0.564 x 0.822 x 0.424

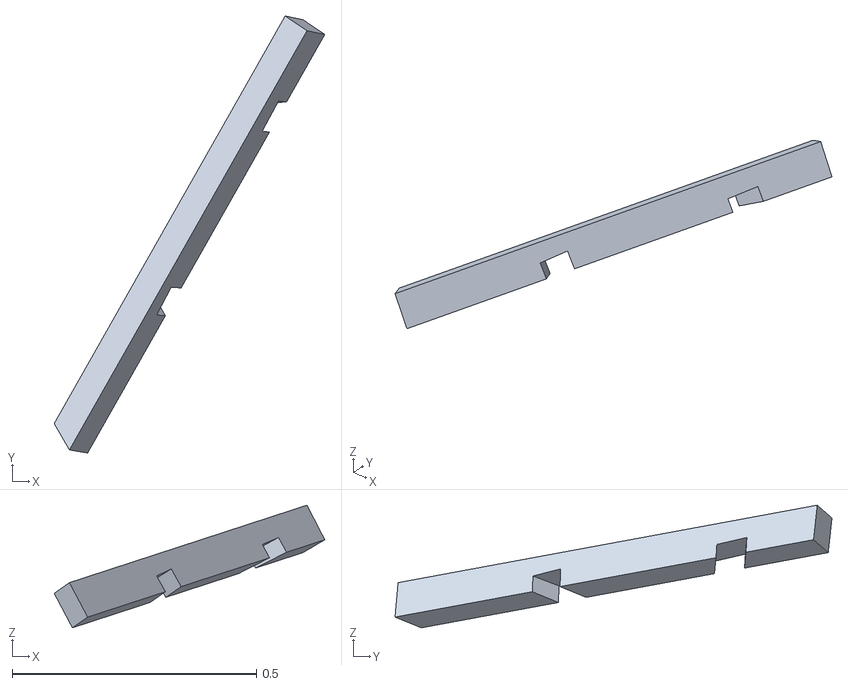
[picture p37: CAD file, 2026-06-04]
web_data/beam/a17/a17.stl
0.554 x 0.895 x 0.251

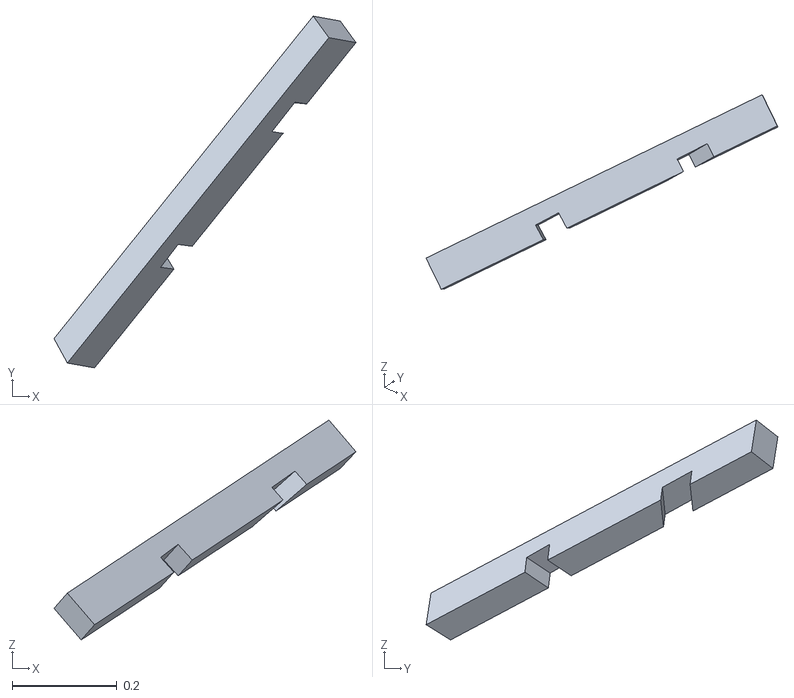
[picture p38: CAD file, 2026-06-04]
web_data/beam/a18/a18.stl
0.575 x 0.67 x 0.419

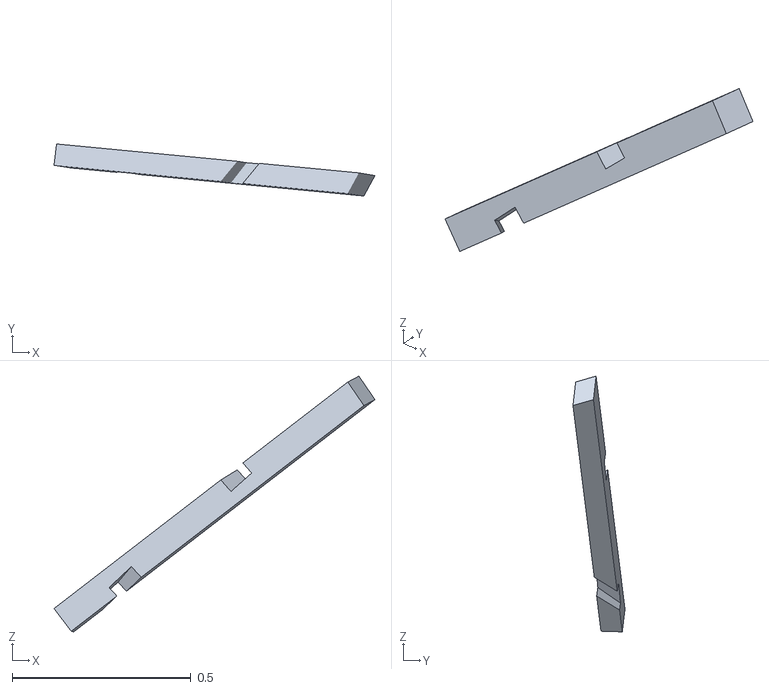
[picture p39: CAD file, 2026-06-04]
web_data/beam/a19/a19.stl
0.898 x 0.146 x 0.716

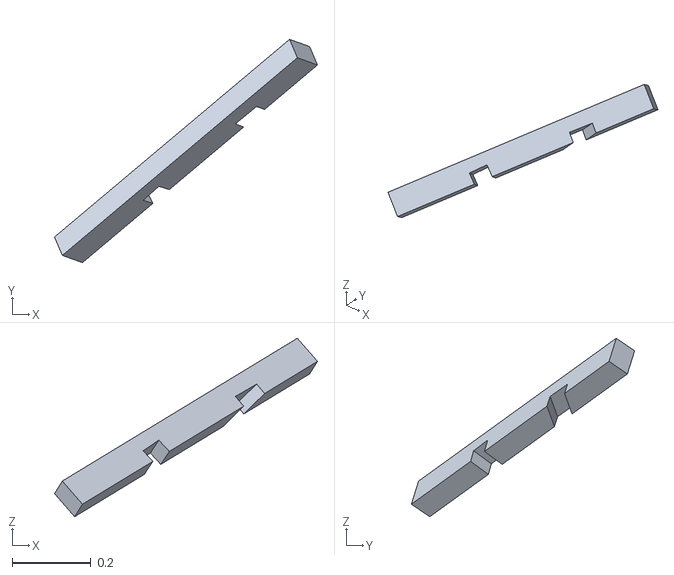
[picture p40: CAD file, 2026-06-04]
web_data/beam/a2/a2.stl
0.669 x 0.568 x 0.454

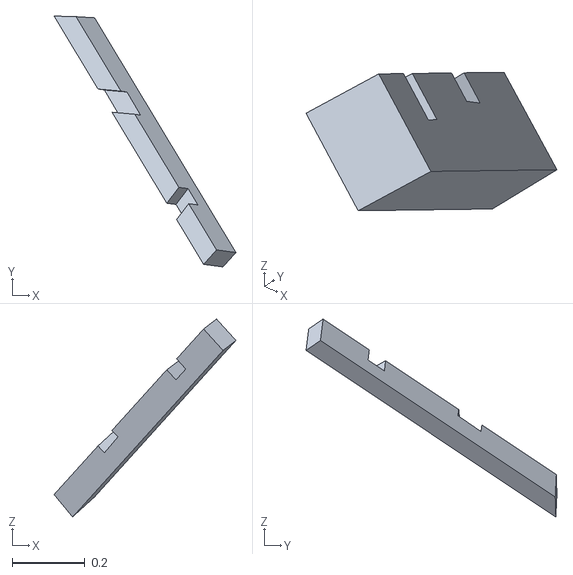
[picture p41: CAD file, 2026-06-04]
web_data/beam/a20/a20.stl
0.501 x 0.691 x 0.545

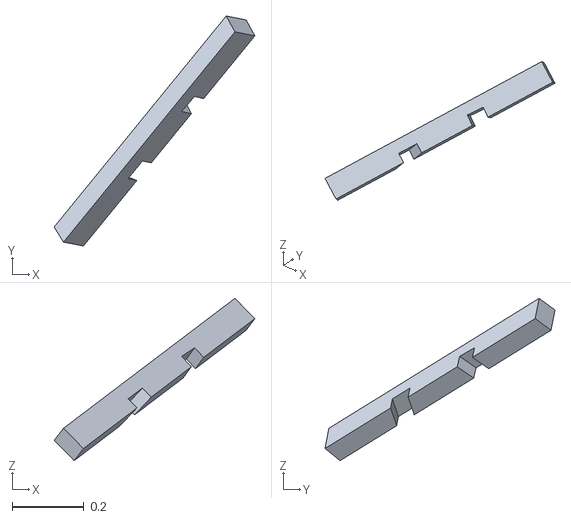
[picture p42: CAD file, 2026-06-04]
web_data/beam/a21/a21.stl
0.56 x 0.641 x 0.452

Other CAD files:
web_data/beam/a22/a22.stl
web_data/beam/a23/a23.stl
web_data/beam/a24/a24.stl
web_data/beam/a25/a25.stl
design/a03_stencil.3dm
design/baked-model-current.3dm
design/ca2_rhino-file_FocusWork.3dm
web_data/beam/a26/a26.stl
web_data/beam/a27/a27.stl
web_data/beam/a28/a28.stl
web_data/beam/a29/a29.stl
web_data/beam/a3/a3.stl
web_data/beam/a30/a30.stl
web_data/beam/a31/a31.stl
web_data/beam/a32/a32.stl
web_data/beam/a33/a33.stl
web_data/beam/a34/a34.stl
web_data/beam/a35/a35.stl
web_data/beam/a36/a36.stl
web_data/beam/a4/a4.stl
web_data/beam/a5/a5.stl
web_data/beam/a6/a6.stl
web_data/beam/a7/a7.stl
web_data/beam/a8/a8.stl
web_data/beam/a9/a9.stl
web_data/beam/b1/b1.stl
web_data/beam/b10/b10.stl
web_data/beam/b11/b11.stl
web_data/beam/b12/b12.stl
web_data/beam/b13/b13.stl
web_data/beam/b14/b14.stl
web_data/beam/b15/b15.stl
web_data/beam/b16/b16.stl
web_data/beam/b17/b17.stl
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

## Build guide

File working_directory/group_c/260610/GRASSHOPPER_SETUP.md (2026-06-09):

# Production Pipeline - Grasshopper Integration Guide

## Overview

The production pipeline consists of three stages, each with a separate Python component:

```
Stage 1: NUMBERING          Stage 2: NAMING              Stage 3: PACKING
━━━━━━━━━━━━━━━━━           ━━━━━━━━━━━━━━━━━            ━━━━━━━━━━━━━━━
timber_model               timber_model_numbered        timber_model_named
    ↓                            ↓                            ↓
run_numbering()            run_module_naming()          run_packing()
    ↓                            ↓                            ↓
Adds attributes:           Adds attributes:             Outputs 2D layout:
• module (A-F)             • engraving_ref_side         • arr_boxes
• number (1,2,...)         • engraving_start_x/y        • arr_names
• display_name (A1)        • text_height                • stock_info
• beam_id (a1)             
                           Adds Text features ✓
```

---

## Component 1: Complete Pipeline (gh_production_pipeline.py)

**Use when**: You want to run all three stages in one component.

### Setup in Grasshopper

1. Create a new **Python** component in Grasshopper
2. Copy entire content of `gh_production_pipeline.py` into the script editor
3. Add inputs (right-click component → Input → New):

| Input Name | Type | Description |
|---|---|---|
| timber_model | Item | TimberModel object |
| Index | List | Module indices (from spatial partitioning) |
| RunExport | Boolean | Export statistics to file |
| OutputFolder | String | Path for exports |
| TextHeight | Number | Text height (mm) - default 0.03 |
| Origin | Point | Layout start point (default 0,0,0) |
| SawGap | Number | Gap between beams (m) - default 0.01 |
| LabelOffset | Number | Z-offset for labels (m) - default 0.1 |
| PricePerMeter | Number | Cost per meter (EUR) - default 10.0 |

4. Add outputs (right-click component → Output → New):

```
Stage 1 (Numbering):
out_1: debug_out
out_2: info_out
out_3: json_export_out
out_4: a_geom_out
out_5: b_geom_out
out_6: c_geom_out
out_7: d_geom_out
out_8: e_geom_out
out_9: f_geom_out
out_10: timber_model_numbered

Stage 2 (Naming):
out_11: named_labels
out_12: ordered_beams
out_13: engraving_refs
out_14: naming_report
out_15: timber_model_named

Stage 3 (Packing):
out_16: arr_boxes (geometry)
out_17: arr_names (geometry)
out_18: arr_lines (geometry)
out_19: max_length (number)
out_20: dimensions (list)
out_21: num_txt (list)
out_22: stock_info (list)
out_23: packing_report (string)
out_24: timber_model_final
```

### Example Connection

```
[Load TimberModel] 
       ↓
[Python: gh_production_pipeline.py]
       ↓ out_10 (timber_model_numbered)
     ↓ out_15 (timber_model_named)
     ↓ out_16 (arr_boxes) → [Mesh/BRep Display]
     ↓ out_17 (arr_names) → [Text Display]
     ↓ out_22 (stock_info) → [JSON Export]
     ↓ out_23 (packing_report) → [Text Panel]
```

---

## Component 2: Packing Stage Only (gh_packing_only.py)

**Use when**: You already have `timber_model_named` (from numbering + naming steps).

### Setup in Grasshopper

1. Create a new **Python** component
2. Copy content of `gh_packing_only.py`
3. Add inputs:

| Input Name | Type | Default |
|---|---|---|
| timber_model | Item | (required) |
| Origin | Point | 0,0,0 |
| SawGap | Number | 0.01 |
| LabelOffset | Number | 0.1 |
| PricePerMeter | Number | 10.0 |

4. Add outputs:

```
arr_boxes (geometry)
arr_names (geometry)
arr_lines (geometry)
max_length (number)
dimensions (list)
num_txt (list)
stock_info (list)
packing_report (string)
```

---

## Required Python Environment

**venv**: `ca-fs26-focus-work`

Dependencies:
- COMPAS Timber (for `compas_timber.fabrication.Text`)
- Rhino.Geometry (IronPython)
- Standard library: sys, math, traceback

The component uses `DevTools.ensure_path()` to automatically set COMPAS paths.

---

## Data Flow: Attributes Through Pipeline

### After run_numbering()
```python
beam.attributes = {
    "module": "A",           # Letter A-F
    "number": 1,             # Sequential
    "display_name": "A1",    # Human-readable
    "beam_id": "a1"          # Lowercase ID
}
```

### After run_module_naming()
```python
beam.attributes = {
    # ... previous attributes ...
    "engraving_ref_side": 2,          # Face index (0-5)
    "engraving_start_x": 0.15,        # Position on face (m)
    "engraving_start_y": 0.20,        # Position on face (m)
    "text_height": 0.05               # Engraving height (m)
}

beam.features = [
    Text(ref_side_index=2, start_x=0.15, start_y=0.20, text="A1", ...)
]
```

### After run_packing()
```python
# Returns stock_info: list of dicts per beam
stock_info = [
    {
        "beam_id": "a1",
        "display_name": "A1",
        "module": "A",
        "number": 1,
        "nested_position_x": 2.35,     # Position in 2D layout (m)
        "nested_length": 3.15,         # Length in layout (m)
        "has_text_feature": True
    },
    # ... more beams ...
]
```

---

## Troubleshooting

### "ERROR: Could not import pipeline modules"
**Cause**: Path to scripts not found
**Fix**: Edit the `sys.path.insert()` line to match your working directory:
```python
sys.path.insert(0, r"YOUR_PATH_HERE/working_directory/group_c/260608")
```

### "ERROR: No beams in timber_model"
**Cause**: Empty or invalid model
**Fix**: Check that timber_model is properly loaded from upstream component

### "WARNING: Some beams missing attributes"
**Cause**: Beams weren't processed by run_numbering() first
**Fix**: Connect output from Stage 1 (out_10) to Stage 2 input

### Text features not visible in Rhino
**Cause**: Text features exist on model but not rendered in viewport
**Fix**: This is expected—Text features are metadata for CAM software, not viewable geometry. Use `arr_names` output for visualization.

---

## Production Workflow

### Setup
1. Load timber model from JSON/Rhino
2. Run numbering (assigns module + number attributes)
3. Run module naming (adds Text features + engraving attributes)
4. Run packing (creates 2D layout)

### Output
- **arr_boxes**: Send to CNC nesting
- **arr_names**: Print for verification
- **stock_info**: Export to CAM software (CSV/JSON)
- **timber_model_final**: Save for downstream fabrication (Drilling, Joinery, etc.)

### Export
```python
import json

# Save stock metadata for CAM
with open("stock_layout.json", "w") as f:
    json.dump(stock_info, f, indent=2)

# Save packing report
with open("production_report.txt", "w") as f:
    f.write(packing_report)
```

---

## Example Grasshopper Canvas

```
┌─────────────────┐
│ Load TimberModel│
└────────┬────────┘
         │
         v
┌─────────────────────────────────────────┐
│ Python: gh_production_pipeline.py       │
│                                         │
│ INPUT:                                  │
│ [timber_model] ─────────────────┐       │
│ [Index] ─────────────────┐       │       │
│ [RunExport] ─────────────┼───────┤       │
│ [OutputFolder] ──────────┼───────┤       │
│ [TextHeight] ─────────────┼───────┤       │
│ [Origin] ────────────────┼───────┤       │
│ [SawGap] ─────────────────┼───────┤       │
│ [LabelOffset] ────────────┼───────┤       │
│ [PricePerMeter] ──────────┼───────┤       │
│                           │       │       │
└─────────────────────────────────────────┘
  │      │      │      │      │      │  
  │      │      │      │      │      ├──> [out_16] arr_boxes
  │      │      │      │      │      ├──> [out_17] arr_names (Display)
  │      │      │      │      │      ├──> [out_22] stock_info (JSON Export)
  │      │      │      │      │      └──> [out_23] packing_report (Panel)
  │      │      │      │      │
  └──────┴──────┴──────┴──────┘
         │
         v
   [Continue to CAM]
```

---

## Next Steps

1. **Verify pipeline**: Run complete workflow and check all attributes are stored
2. **Test packing**: Visualize `arr_boxes` + `arr_names` in Rhino
3. **Export**: Save `stock_info` to JSON for CAM software
4. **Fabrication**: Use `timber_model_final` (with Text features) for downstream Drilling/Joinery components

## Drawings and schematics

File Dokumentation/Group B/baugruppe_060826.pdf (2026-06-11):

0.118m | Det: Fund_Schraubfund

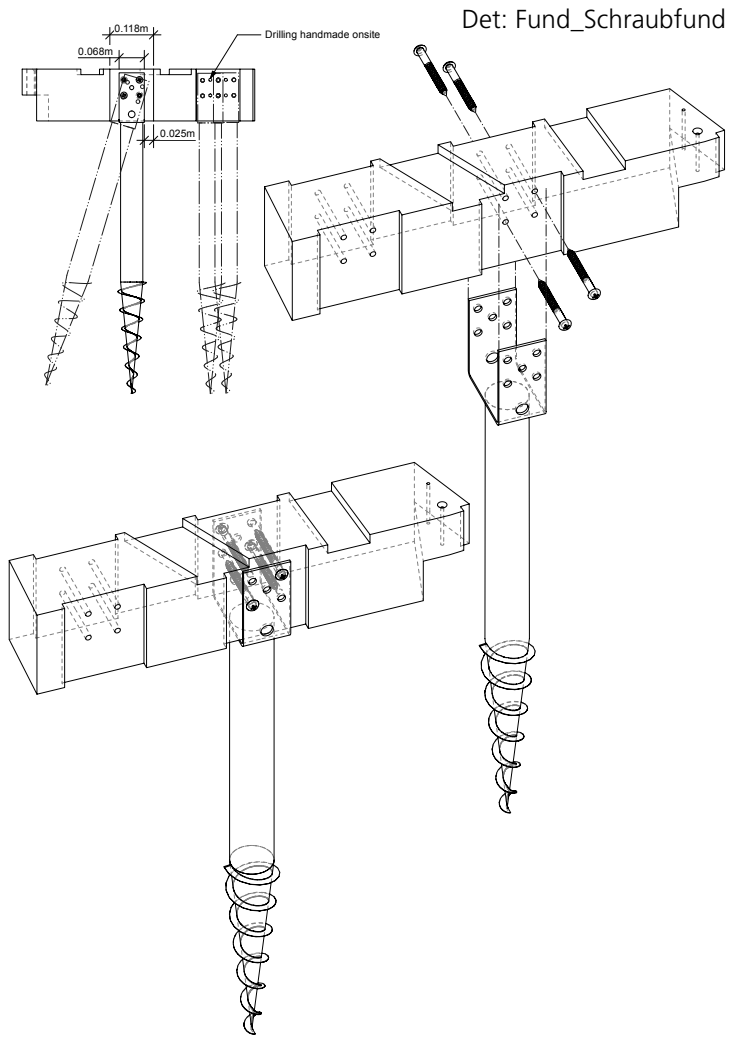
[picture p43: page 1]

Drilling handmade onsite

# Det: Fund_Fund_Platte

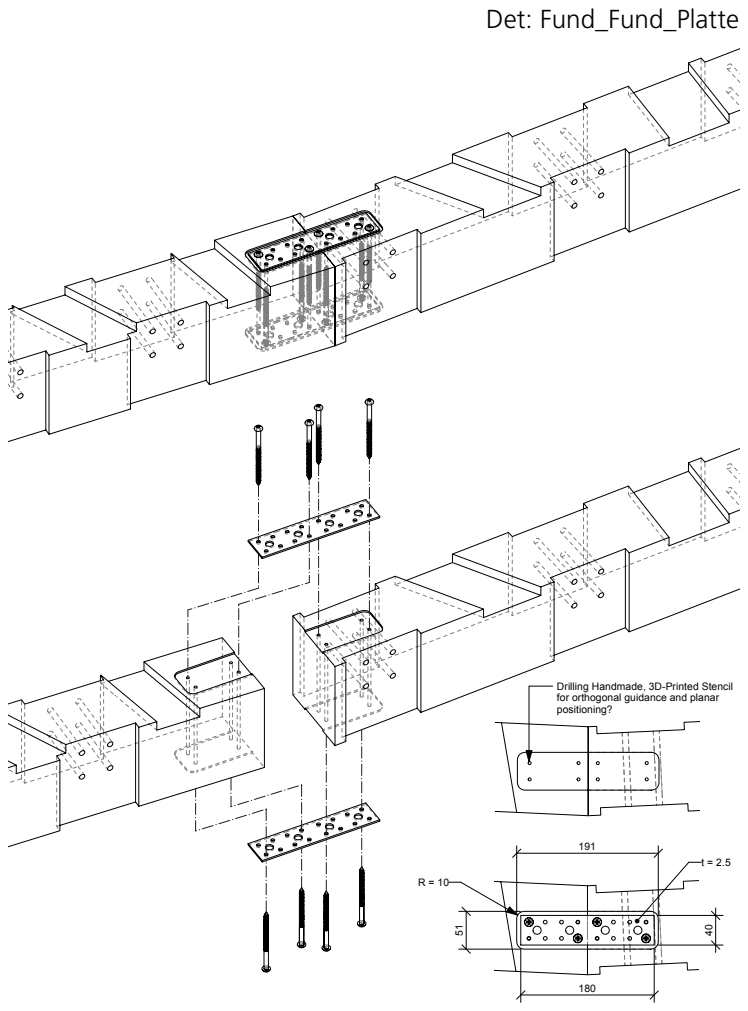
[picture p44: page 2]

Drilling Handmade, 3D-Printed Stencil
for orthogonal guidance and planar
positioning?

# Det: Fund_Fund_Lap

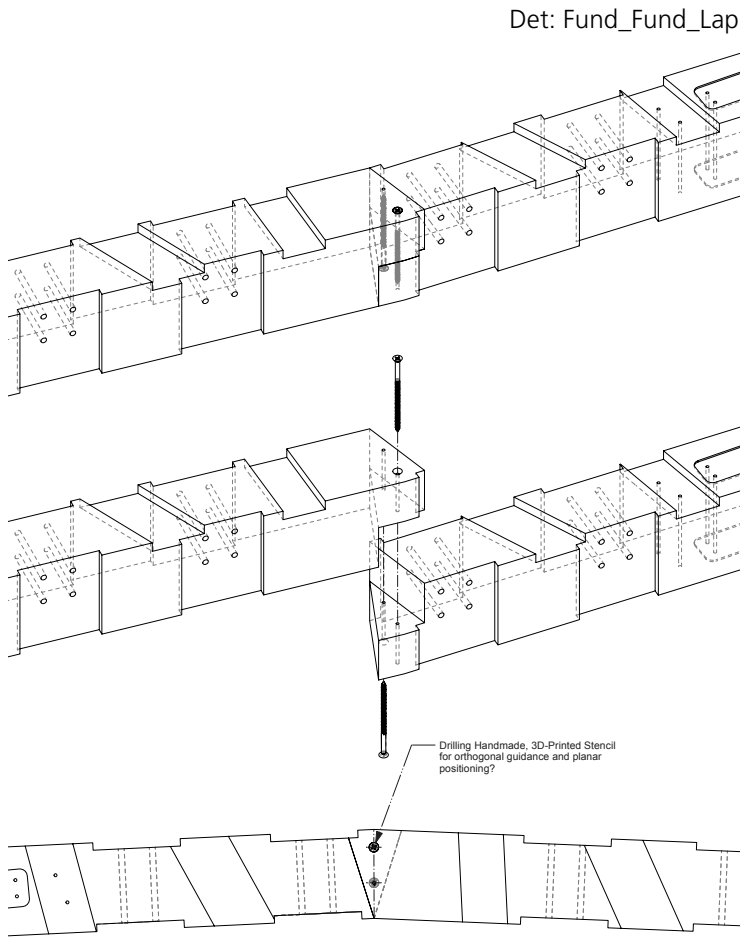
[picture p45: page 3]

Drilling Handmade, 3D-Printed Stencil
for orthogonal guidance and planar
positioning?

# Det: Fund_Inner

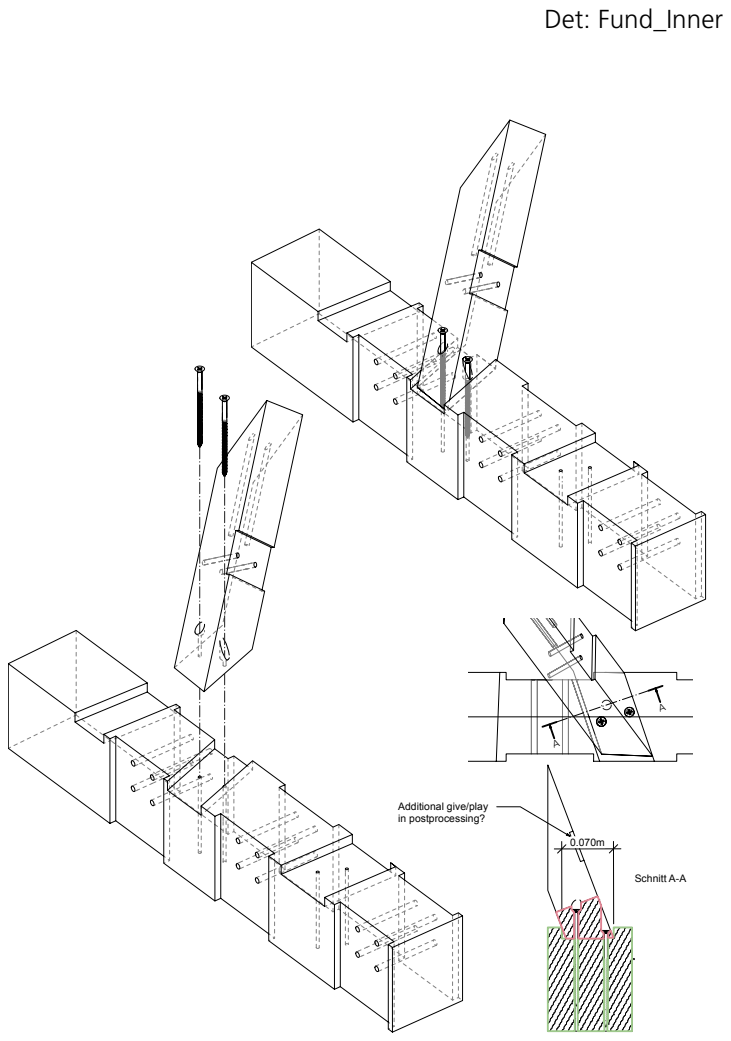
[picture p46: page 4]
Schnitt A-A

Additional give/play
in postprocessing?

# Det: Fund_Arch

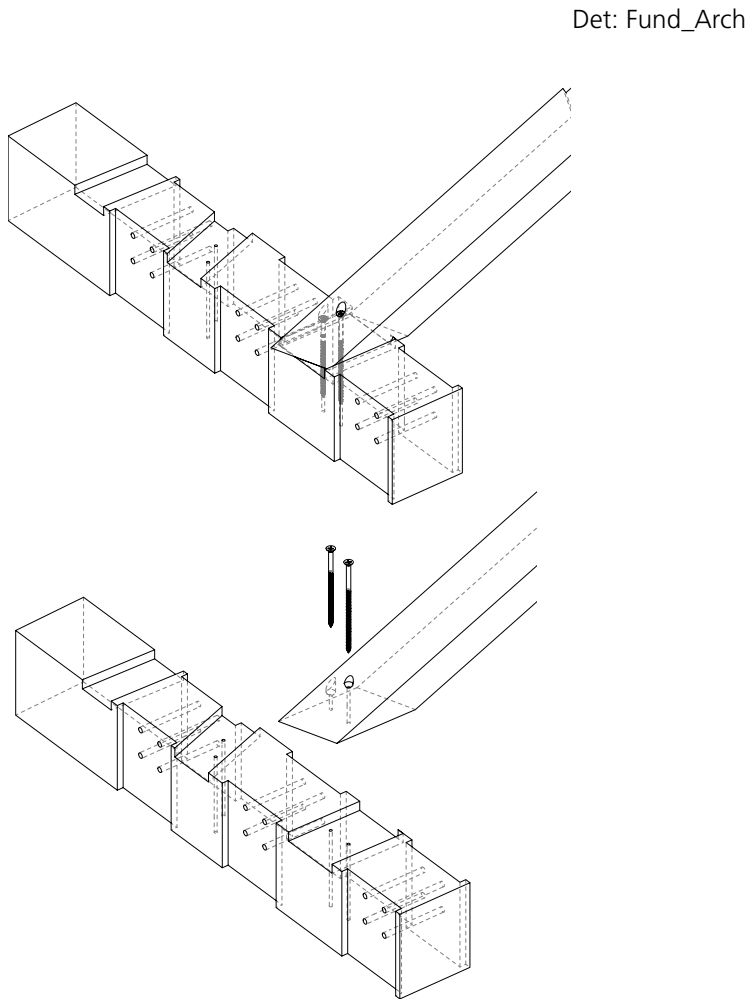
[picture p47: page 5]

# Det: Arch_Inner

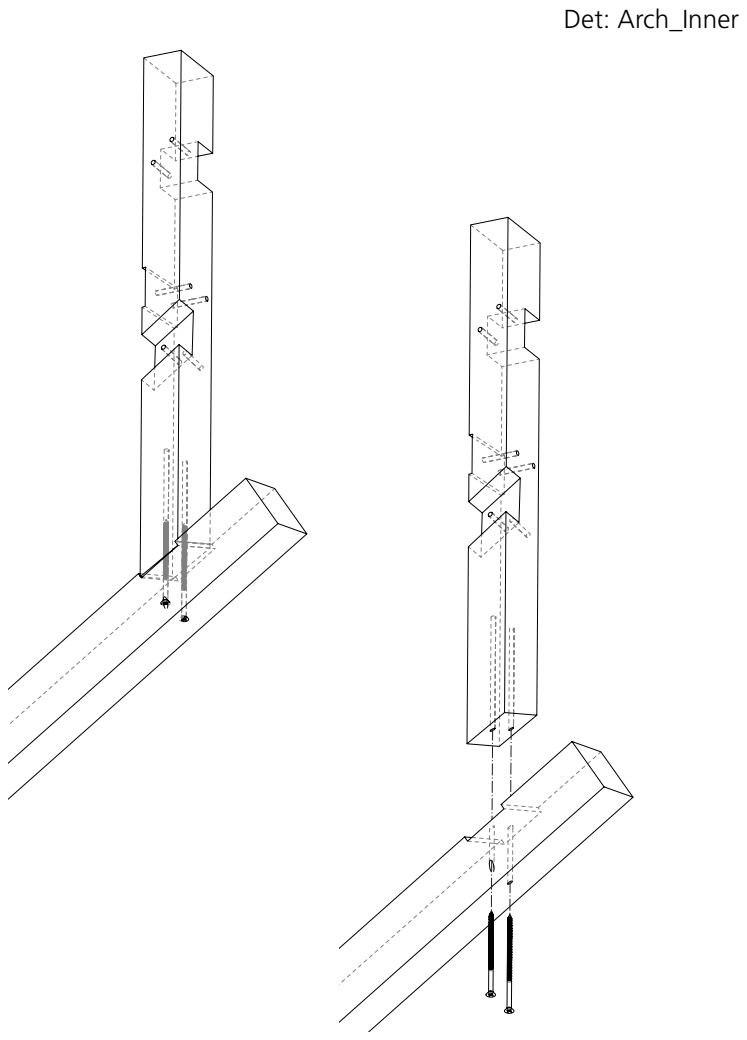
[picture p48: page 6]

# Det: Arch_Arch_Lap

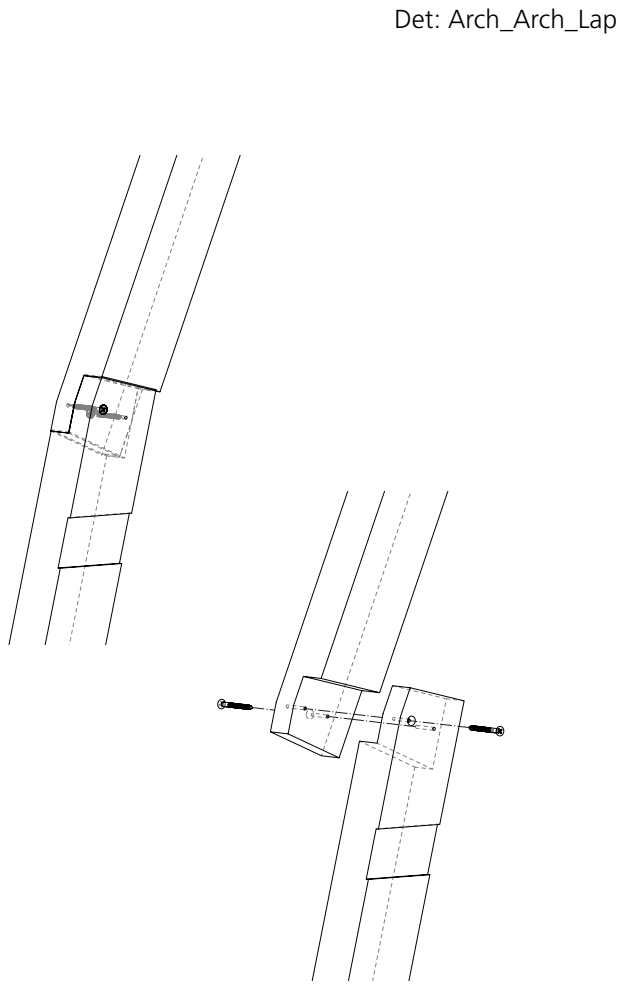
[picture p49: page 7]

# Det: Inner_Inner_X-Lap

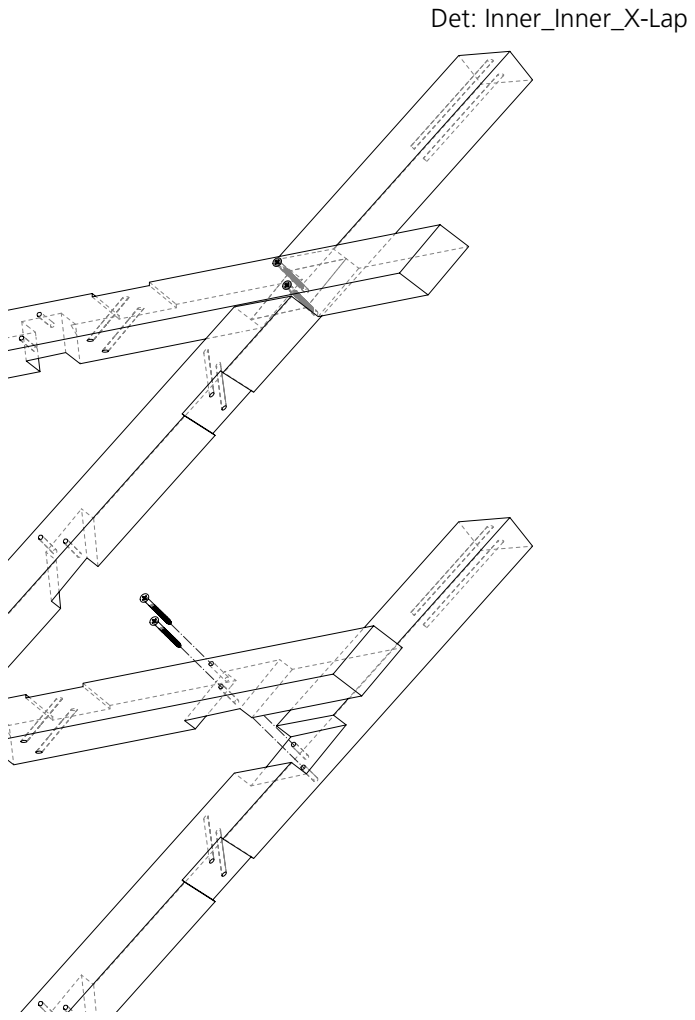
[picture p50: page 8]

# Det: Inner_Inner_T-Butt

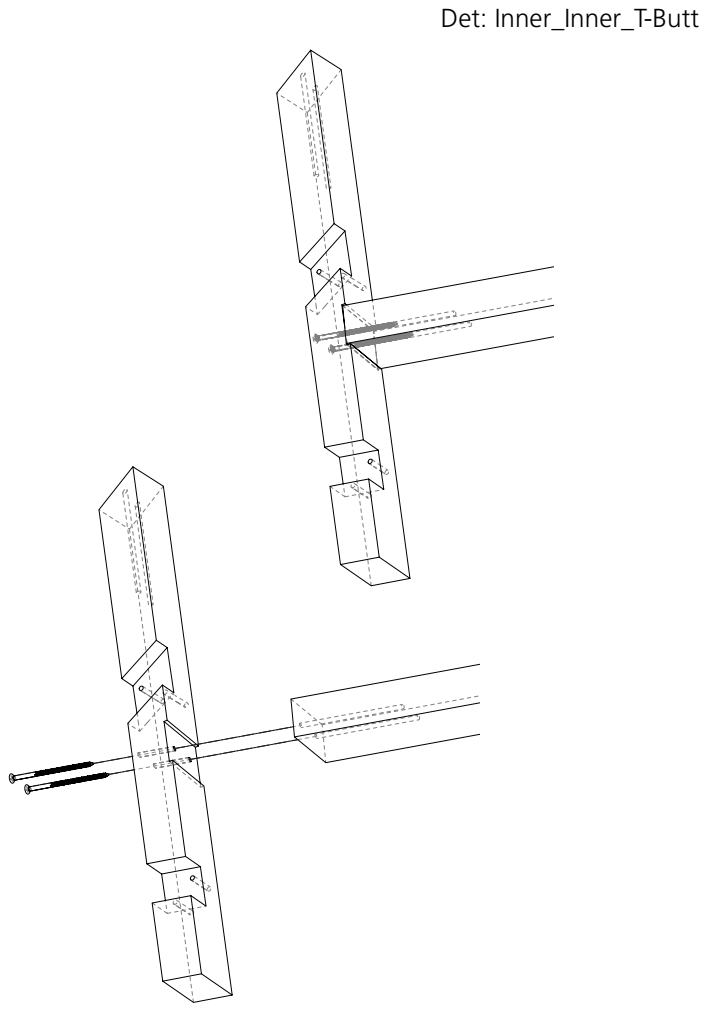
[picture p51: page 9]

# Det: Arch_Arch_Platte

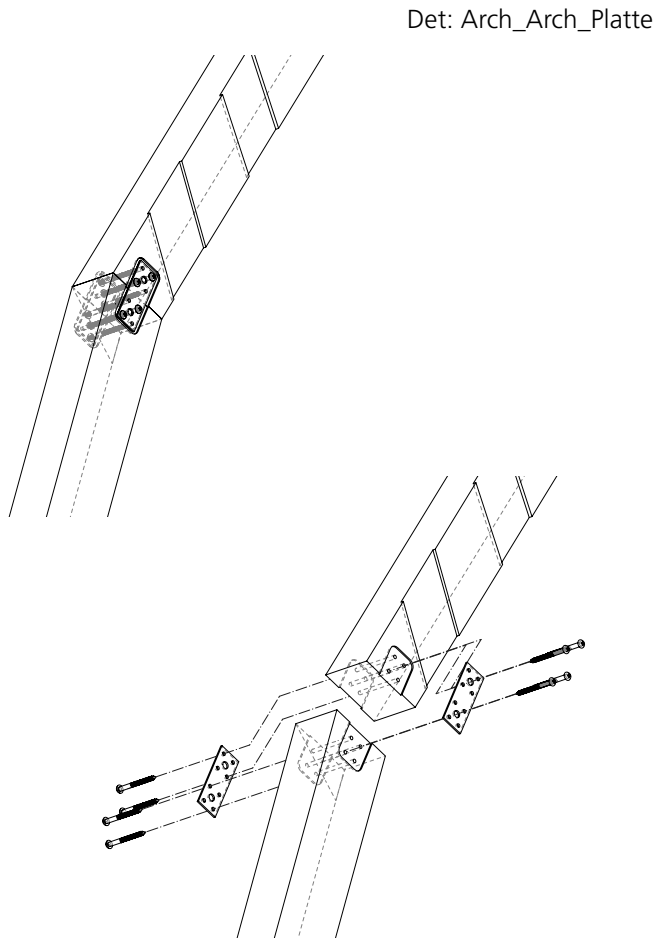
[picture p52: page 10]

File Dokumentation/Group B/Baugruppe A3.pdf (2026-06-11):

# Baugruppe

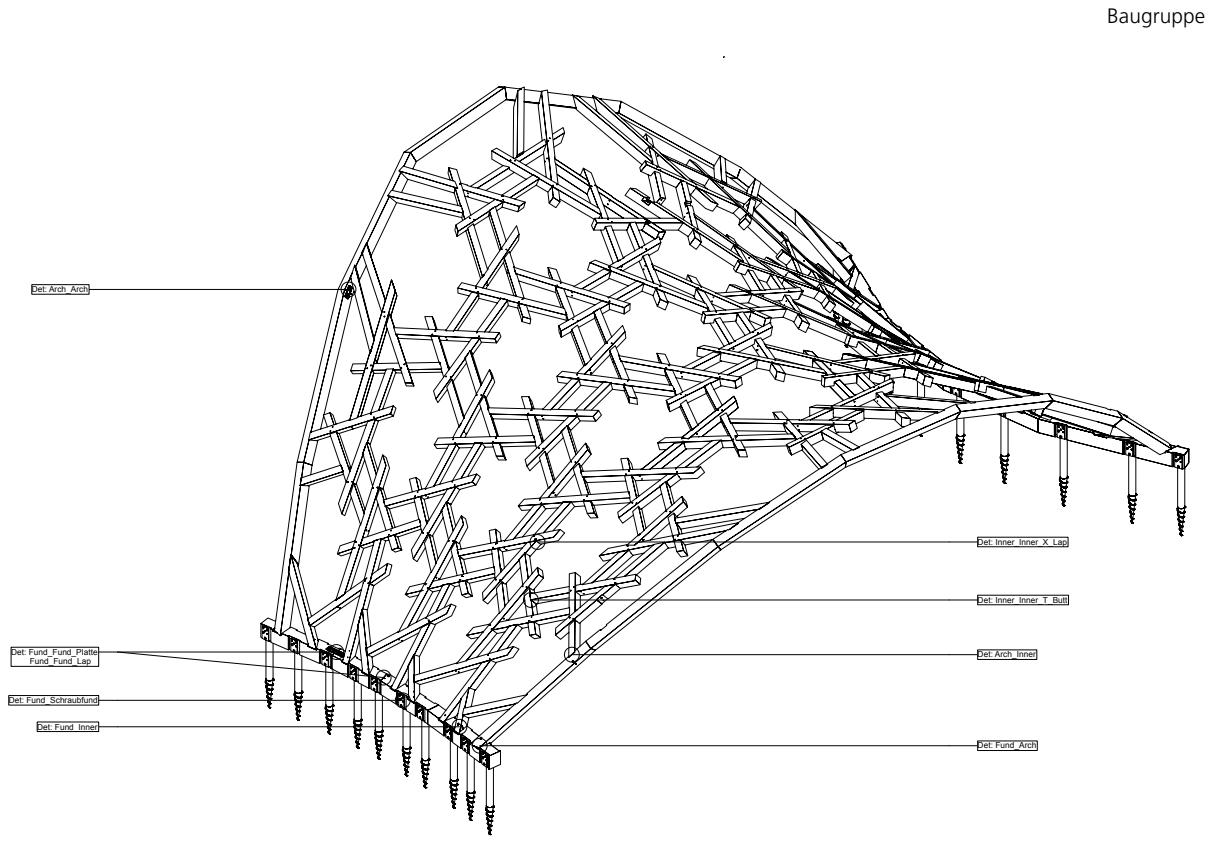
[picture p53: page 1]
Det: Fund_Fund_Platte Fund_Fund_Lap; Det: Fund_Schraubfund; Det: Fund_Inner; Det: Fund_Arch; Det: Arch_Arch; Det: Inner_Inner_X_Lap; Det: Inner_Inner_T_Butt; Det: Arch_Inner

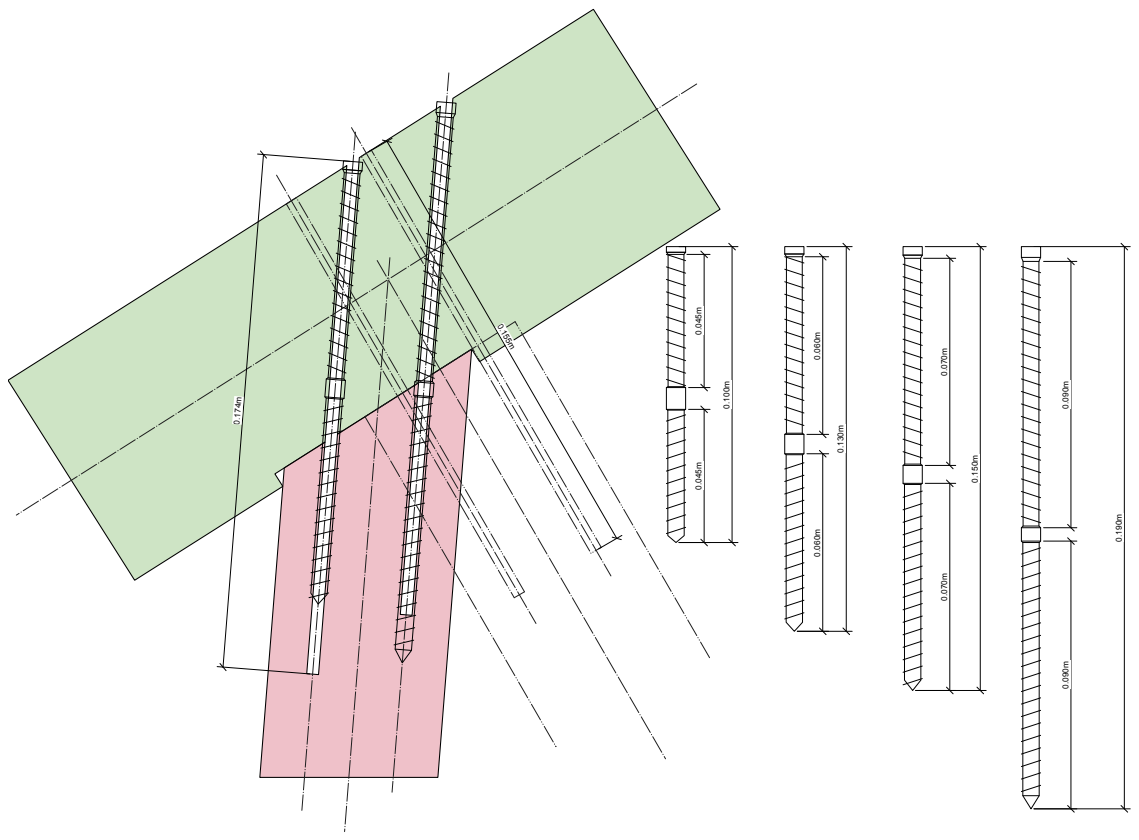
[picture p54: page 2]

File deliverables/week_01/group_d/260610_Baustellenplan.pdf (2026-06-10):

Grenzabstand; Hauptzugang Feuerwehr; Zone A; Zone C; Zone E; Zone D Werkzeug; Zone B; Umschlag / Abbindplatz; Lager; Nebenzugang; Sammelplatz; Zelt 4x6m; Hauptzugang; Fluchtweg; Freizuhaltende Fläche; Fluchtausgang; Medikit / Erstversorgung

Stellfläche Feuerwehr
fläche (für Fz bis 18 t)

Feuerwehrzufahrt und Bewegungs-
(für Fz bis 18 t)

First-Aid / Welfare

BAUVORHABEN: Pavillon Quartiergarten Hard Bullingerstrasse 90, 8004 Zürich | AUFTRAGGEBER: ETH Zürich | PLANVERFASSER: Gramazio Kohler Research ETH Zürich

Wichtige Pflanze Bestand

Feuerwehrzufahrt (für Fz bis 18 t)

Zone A - Crane Operating Area

Bestehende Pflanze wird vor
Baubeginn versetzt

Stellfläche Feuerwehr (für Fz bis 18 t)

Zone B - Active Construction

PLANNUMMER: 1.2 | PLANTITEL: Construction Site Plan | MASSSTAB: 1:100 | PLANGRÖSSE: A3 | PROJEKTNUMMER: 409 | GEZEICHNET: | DATUM: | REVIDIERT:

Zone C - Tool & Material store

Zone D - Welfare / first aid

Zone E - Public Perimeter

GSEducationalVersion /Users/mac4ron/Documents/ETH/Coding Architecture/Focus Work/Baustellenplan_29.pln

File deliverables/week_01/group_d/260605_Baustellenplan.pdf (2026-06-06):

Grenzabstand; Hauptzugang Feuerwehr; Stellfläche Feuerwehr; Zone C Zone A; Zone E; Werkzeug; Zone B; Umschlag / Abbindplatz; Lager; Hauptzugang; Nebenzugang; Zelt A; Zelt B 4x8m; Fluchtweg; Freizuhaltende Fläche; Fluchtausgang; Sammelplatz; Medikit / Erstversorgung

Feuerwehrzufahrt und Bewegungs-
(für Fz bis 18 t)

fläche (für Fz bis 18 t)

Zone D
First-Aid / Welfare Sammelplatz

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

Wichtige Pflanze Bestand

Feuerwehrzufahrt (für Fz bis 18 t)

Zone A - Crane Operating Area

Stellfläche Feuerwehr (für Fz bis 18 t)

Zone B - Active Construction

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

Zone C - Tool & Material store

Zone D - Welfare / first aid

Zone E - Public Perimeter

GSEducationalVersion /Users/mac4ron/Documents/ETH/Coding Architecture/Focus Work/Baustellenplan_29.pln

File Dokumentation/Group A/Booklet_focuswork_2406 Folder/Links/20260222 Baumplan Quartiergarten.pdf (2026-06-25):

2

3

Apfelbaum 'Berlepsch rot'; Zwetschge 'Davrovice'; 'Japanische Fasserbanane'; Mirabelle 'von Nancy'; Aprikose 'Elsa'; Lavendelstreifen; Holunder, Hartriegel; Apfelbaum- Wildling; Sämmling: unbestimmte Pflaume; schwarzer Holunder; Zwetschge; Birnenbaum; Weidenhaus; Olivenbaum; Hartriegel; Kirschbaum- Wildling; Feigenbaum; Blockhaus; Hühnerstahl; Langbeete; Gewächshaus; Werkzeugpergola; Beeren; Brombeeren; Erdbeeren; Himbeeren; Steinhaufen, Artischoken; Pizza-Ofen; Kinderhaus; Gästerpergola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

1 Apfel: Malus domestica 'Zürichapfel' Regina S.

2 Kaki: Diospyros kaki 'Tipo' Susanne L.

3 Quitte: Cydonia oblonga 'Leskovac' Christine A.

4 Apfel: Malus domestica 'Cox Orange' Rhababergruppe, Nicole G.

5 Süsskirsche: Prunus avium 'Sunburst' Shirana S.

'Grosse grüne Reineclaude'

6 Lotuspflaume: Diospyros lotus
Irene D.
7 Eberesche: Sorbus aucuparia (Strauchform)
Hühnergruppe, Claudia K.
8 Sauerkirsche: Prunus cerasus 'Schattenmorelle' Karin S.

Feige Ficus carica

weisse Maulbeere Morus alba

9 Apfelquitte: Cydonia oblonga 'Cydolus' Susanne L.

Gertrud- Franck- Garten

weidenblättrige Birne Pyrus salicifolius

10 Weinbergpfirsich: Prunus persica 'Weinbergpfirsich' Nicole G.

11 Aprikose: Prunus armeniaca
In Abklärung
12 Pfirsich: Prunus persica 'Honey Sun' Zucchettifeld, Theo L.

japanische Wollmispel Eriobotrya japonica

13 Minikiwi: Actinidia arguta Vakant

14 Aprikose: Prunus armeniaca Margret P.

Löhrpflaume Prunus Sorte

Mispel Mespilus germanica

15 Williamsbirne: Pyrus communis 'Williams Christ' Zwetschge: Prunus domestica Manuela S.

Zuc heti-Beet

16 Olivenbäume: Olea europaea Kräutergruppe

17 Granatäpfel: Punica granatum
Milica K.

1 Apfel: Malus domestica 'Berlepsch rot' Claudia K.

2 Reineclaude: Prunus domestica 'Gr. gr. Reineclaude' David A.

3 Zwetschge: Prunus domestica 'Davrovice' Karin S.

4 Kletterobst-Pergola (versch. Kiwis, Reben, Beeren)
5 Japanische Faserbanane: Musa basjoo
6 Mirabelle: Prunus domestica 'Mirabelle de Nancy' Kinderkollektiv, Bernadette T.

Mandelbaum
Prunus dulcis 'Amanda'

7 Aprikose: Prunus armeniaca 'Elsa' Feige: Ficus carica Martin T.

8 Schwarze Maulbeere: Morus nigra 'Wellington' Bernadette T.

Wildlinge und Bäume Naturgarten

Bäume, die von der Baumschnittgruppe
beschnitten werden

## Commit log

2026-05-28 feat: add RF system, timber model, and Grasshopper component scripts
    Core modules for reciprocal frame generation (standard, advanced/Timo,
    hybrid), timber model creation (category-based and topology-aware),
    meshing, modifiers and relaxation, plus extras for 3D printing, packing
    stats, structural analysis, and toolpath. Grasshopper helpers for
    building, saving, and loading the RF system from centerlines.
2026-05-28 chore: add design outputs, timber model, and project assets
    Includes the Rhino source file and analysis renders under design/, the
    final hexmesh timber model JSON, project images (perspective render,
    3D model, reciprocal frame, assembly sequence, cumulative radiation),
    and the poster and presentation PDFs.
2026-05-28 docs: add project README with embedded images
    Covers RF system architecture, timber joinery, key innovations,
    challenges and solutions, file structure, usage, and results. Embeds
    the perspective render, reciprocal frame diagram, 3D model preview,
    assembly sequence, and cumulative radiation analysis.
2026-05-28 docs: add workshop group folders and link them in README
    Adds group_a, group_b, group_c, group_d, each with a README explaining
    the pipeline handoff (a → b → c → d, each group reads from the previous
    and writes its output into its own folder) and a participants list. The
    top-level README gets a Workshop Groups section linking the four.
2026-05-29 rework of submission file
    [ca2_rhino-file_FocusWork.3dm]
2026-05-29 updates to base file
    [ca2_rhino-file_FocusWork.3dm]
2026-05-29 prepped timber model creator, surface construction
    [ca2_rhino-file_FocusWork.3dm]
2026-05-29 small changes
    [ca2_rhino-file_FocusWork.3dm]
2026-05-31 Fix requirements and add missing robot files
    [base.dae.obj, base.obj, base.stl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]
2026-06-02 TButt Joints
2026-06-02 Birds Mouth Joints
2026-06-03 arch - base joint
2026-06-03 beam foldes
    [beam_1.stl]
2026-06-03 drilling holes code test
2026-06-03 resolve the drilling error
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2026-06-03 Drilling python file and grasshopper component python script
2026-06-03 beams website
    [a1.stl, a10.stl, a11.stl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]
2026-06-04 timber model debug / duplicate timber joint fix
2026-06-04 new joints after structural analysis
2026-06-04 Double screw tbutt and summary
2026-06-04 failed drills labels
2026-06-04 more joint cleaning + rotation + live edit
2026-06-04 260605 stats and arrange maybe
    [base.dae.obj, base.obj, base.stl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]
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2026-06-05 stencil group c
    [a03_stencil.3dm]
2026-06-05 stencil update
    [a03_stencil.3dm]
2026-06-05 preferred face tbutt joint
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2026-06-05 Preferred t but joint for base + general live edit corrections
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2026-06-06 web data update
    [a1.stl, a10.stl, a11.stl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]
2026-06-06 update webdata
    [a1.stl, a10.stl, a11.stl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]
2026-06-06 plate layout
    [a03_stencil.3dm]
2026-06-08 rf drilling changes and copies
2026-06-08 3D Print settings changed to Bambu A1
2026-06-08 aggiornamento file
    [base.dae.obj, base.obj, base.stl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]
2026-06-08 changed plate viz to correct dimensions
2026-06-08 rf_drilling Tbutt joint fix
2026-06-08 adjusted stencil
    [a03_stencil.3dm]
2026-06-08 separated frame and plate beams
2026-06-08 nearly finished
    [a03_stencil.3dm]
2026-06-08 trial file group c
    [a03_stencil.3dm]
2026-06-08 rf drilling almost foundation
2026-06-08 adjusted to new foundation points
    [a03_stencil.3dm]
2026-06-09 butt joints correction - live edit
2026-06-09 adjusted load model for custom joints
2026-06-09 Live edit for butt joints
2026-06-09 Stencil not done
    [a03_stencil.3dm]
2026-06-09 custom lap joint fix
2026-06-09 Stencil almost done
    [a03_stencil.3dm]
2026-06-09 rf_drilling categorization of screws
2026-06-09 custom lap joints update
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2026-06-10 rf drilling only one beam drilled
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2026-06-10 drilling at less then 40 degree angle
2026-06-10 beam local frame and blank export for web data
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2026-06-10 toogle for base joints
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2026-06-10 layout di prima infopanel
2026-06-10 rf drilling almost tbutt 40 degrees
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2026-06-10 new webdata
    [a1.stl, a10.stl, a11.stl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]
2026-06-10 webdata base l miter joints
    [a13.stl, a14.stl, a14_blank.stl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]
2026-06-11 deleted old files
    [a03_stencil.3dm]
2026-06-11 arrangement folder
    [a03_stencil.3dm]
2026-06-11 rf drilling _ update
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2026-06-11 drilling process grasshopper file edit
2026-06-11 copy files
    [a03_stencil.3dm]
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2026-06-11 web data
    [a10.stl, a10_blank.stl, a10_features.stl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]
2026-06-11 cutoff lap joint reverted - non functioinal
2026-06-11 new modules
    [a1.stl, a10.stl, a10_blank.stl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]
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2026-06-11 try out folder
    [a03_stencil.3dm]
2026-06-12 new modules website
    [a15.stl, a17.stl, a22.stl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]
2026-06-12 Make sure that custom StencilPlate serializes correctly with a standard dtype (data type) equals to compas_timber's Plate class
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2026-06-12 Stencil in base file
    [a03_stencil.3dm]
2026-06-12 blank lengths stencil
    [a03_stencil.3dm]
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2026-06-12 Revert "update metal plates"
    This reverts commit 26fcffa86c04c75da4e0d9e227d2ff692c513ed8.
2026-06-12 deleted old file and folder
    [a03_stencil.3dm]
2026-06-12 labels stencil
    [a03_stencil.3dm]
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2026-06-14 plate cutting feature
    [a03_stencil.3dm]
2026-06-15 Probably fixed the lap created by the metal plates
2026-06-15 8 cm gap for drilling
2026-06-15 missing screws
2026-06-15 stencil final update
    currently being fabricated
2026-06-15 3d print stl
    [pipe support.stl]
2026-06-15 3d print
    [3d piece pipe support.stl]
2026-06-15 3d printing stencil
    [3d printing Stencil.stl]
2026-06-15 drilling tbutt inner inner not working
2026-06-15 screw guide
    [screwguide-export.3dm, screwguide-export.stl]
2026-06-15 screw guide update
    [screwguide-export-2.stl, screwguide-export.3dm]
2026-06-15 Experiment with tilting drilling placement
2026-06-16 hopefully final drilling process
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2026-06-16 drill and plate changes
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2026-06-16 Adjust entry point for screws, add clearance lines, arch cat correction, etc
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2026-06-17 override drillings defined on the front and back ref_side
2026-06-17 revert since this was a special case (hack)
2026-06-19 add extra cut for the ones that dont cut through with a flip
    optimize sorting to adjust the order of machinings based on pre and post flip machinings - (tool optimization)
